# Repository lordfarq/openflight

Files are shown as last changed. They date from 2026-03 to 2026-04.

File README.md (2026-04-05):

<p align="center">

  DIY Golf Launch Monitor using the OPS243-A Doppler Radar.
</p>

<p align="center">
  <a href="https://buymeacoffee.com/colemangolfs">
    
  </a>
</p>

> [!WARNING]
> **This project is in active development.** Features may be incomplete, unstable, or change without notice. Contributions and bug reports are welcome!

## Overview

OpenFlight is an open-source golf launch monitor that uses Doppler radar to measure ball speed, club speed, launch angle, spin rate, and carry distance.

### What It Measures

- **Ball Speed**: 30-220 mph range with ±0.5% accuracy (OPS243-A)
- **Club Speed**: Detected from pre-impact readings (OPS243-A)
- **Smash Factor**: Ball speed / club speed ratio
- **Launch Angle**: Vertical launch measured by K-LD7 angle radar
- **Club Path**: Horizontal aim direction measured by second K-LD7
- **Spin Rate**: Via rolling buffer I/Q analysis (~50-60% detection rate)
- **Carry Distance**: Computed from ball speed, launch angle, and spin

### Hardware at a Glance

| Component | What it does | ~Cost |
|---|---|---|
| OPS243-A Radar | Ball speed, club speed, spin | $249 |
| Raspberry Pi 5 | Runs everything | $60 |
| 7" Touchscreen | Shows shot data | $46 |
| SparkFun SEN-14262 | Sound trigger for spin detection | $18 |
| K-LD7 + EVAL Board (×2) | Launch angle + club path | $400 |
| Power supply + accessories | | $27 |
| **Total** | | **~$800** |

> The K-LD7 angle radars are optional. Without them you still get ball speed, club speed, smash factor, spin rate, and estimated carry. See the [full parts list](docs/PARTS.md) for details and links.

## Getting Started

### 1. Get the parts

See the **[Parts List](docs/PARTS.md)** for everything you need with purchase links.

### 2. Wire it up

Follow the **[Sound Trigger Wiring Guide](docs/sound-trigger-wiring.md)** to connect the SEN-14262 to the OPS243-A. The K-LD7 modules connect via USB — no wiring needed.

### 3. Set up the Pi

Follow the **[Raspberry Pi Setup Guide](docs/raspberry-pi-setup.md)** for OS installation, software setup, radar configuration, and auto-start.

### 4. Hit balls

```bash
# Default: rolling buffer mode with sound trigger
scripts/start-kiosk.sh

# With K-LD7 angle radar
scripts/start-kiosk.sh --kld7 --kld7-angle-offset 13

# Development mode (no hardware)
scripts/start-kiosk.sh --mock
```

Then open http://localhost:8080 or use the touchscreen.

## How It Works

### System Architecture

```
┌─────────────┐  USB/Serial  ┌─────────────┐  Callback   ┌─────────────┐  WebSocket  ┌─────────────┐
│  OPS243-A   │ ───────────▶ │   Launch    │ ──────────▶ │   Flask     │ ──────────▶ │   React     │
│   Radar     │  Speed data  │   Monitor   │  on_shot()  │   Server    │   "shot"    │     UI      │
└─────────────┘              └─────────────┘             └─────────────┘             └─────────────┘
                                                               ▲
┌─────────────┐  USB/Serial                                    │
│ K-LD7 (×2)  │ ──────────────────── angle data ──────────────┘
│ Angle Radar │
└─────────────┘
```

1. **Sound trigger fires** — SEN-14262 detects club impact, triggers OPS243-A HOST_INT
2. **OPS243-A dumps buffer** — Rolling buffer I/Q data is captured and analyzed for ball speed, club speed, and spin
3. **K-LD7 correlates** — The server uses the OPS243-A impact timestamp to find the matching ball burst in the K-LD7 ring buffer, extracting launch angle and club path
4. **Carry computed** — Ball speed + spin + launch angle → carry distance
5. **UI updates** — Shot data emitted via WebSocket to the React frontend

### Doppler Radar Basics

The OPS243-A transmits a 24 GHz signal. When it bounces off a moving object (the golf ball), the frequency shifts proportionally to the object's speed — this is the Doppler effect. At 24.125 GHz, each 1 mph of speed creates a ~71.7 Hz Doppler shift.

### Positioning

Place the radar **3-5 feet behind the tee**, pointing at the hitting area:

```
                Ball Flight Direction
                ======================>

[Tee]  ←--- 3-5 ft ---→  [OPS243-A]  [K-LD7 vertical]  [K-LD7 horizontal]
```

The K-LD7 modules are positioned near the OPS243-A, one mounted vertically (launch angle) and one horizontally (club path / aim direction).

## Configuration

### Radar Settings for Golf

| Setting | Value | Why |
| --- | --- | --- |
| Sample Rate | 20 kHz | Supports up to ~139 mph |
| Buffer Size | 512 | Faster updates (~10-15 Hz)  |
| Min Speed | 10 mph | Filter slow movements |
| Direction | Outbound | Ball moving away from radar |
| Power | Max (0)  | Best detection range |

### Python API

```python
from openflight import LaunchMonitor

with LaunchMonitor() as monitor:
    print("Swing when ready...")
    shot = monitor.wait_for_shot(timeout=60)

    if shot:
        print(f"Ball Speed: {shot.ball_speed_mph:.1f} mph")
        print(f"Est. Carry: {shot.estimated_carry_yards:.0f} yards")
```

## Limitations

- **Cosine error**: If ball doesn't travel directly toward/away from radar, measured speed will be slightly lower than actual
- **Spin detection**: ~50-60% reliable — depends on signal quality and trigger timing
- **K-LD7 speed aliasing**: The K-LD7 max speed is 62 mph, so it's used only for angle/distance, not speed

## Project Structure

```
openflight/
├── src/openflight/
│   ├── ops243.py              # OPS243-A radar driver
│   ├── launch_monitor.py      # Shot detection & club/ball separation
│   ├── server.py              # Flask server, K-LD7 correlation, carry
│   ├── session_logger.py      # JSONL session logging
│   ├── kld7/                  # K-LD7 angle radar
│   │   ├── tracker.py         # Ring buffer, ball/club detection
│   │   └── types.py           # Data types
│   └── rolling_buffer/        # Spin rate detection
│       ├── monitor.py         # Rolling buffer monitor
│       ├── processor.py       # I/Q processing for spin
│       ├── trigger.py         # Trigger strategies
│       └── types.py           # Data types
├── ui/                        # React frontend
├── scripts/                   # Utility & setup scripts
├── docs/                      # Documentation
└── pyproject.toml
```

## Contributing

Contributions welcome! See [CONTRIBUTING.md](CONTRIBUTING.md) for guidelines.

Areas of interest:

- **Better spin detection**: Increase reliability beyond 50-60%
- **K-LD7 signal processing**: Improve ball detection from sparse radar frames
- **Mobile app**: Bluetooth connection to phone

### Running Tests

```bash
uv run pytest tests/ -v
```

## Documentation

- **[Parts List](docs/PARTS.md)** — What to buy
- **[Sound Trigger Wiring](docs/sound-trigger-wiring.md)** — How to wire the sound trigger
- **[Raspberry Pi Setup](docs/raspberry-pi-setup.md)** — Full setup guide
- **[Rolling Buffer & Spin Detection](docs/rolling_buffer_spin_detection.md)** — Spin measurement details
- **[K-LD7 Ball Detection Theory](docs/kld7-ball-detection-theory.md)** — How angle detection works
- **[K-LD7 Session Review](docs/kld7-session-review.md)** — Offline review workflow for session JSONL files
- **[Observability & Log Shipping](docs/observability.md)** — Ship logs to Grafana Cloud
- **[Contributing Guide](CONTRIBUTING.md)** — How to contribute
- **[Changelog](docs/CHANGELOG.md)** — Version history

## License

MIT License - see LICENSE file.

## Acknowledgments

- [OmniPreSense](https://omnipresense.com/) for the OPS243-A radar and documentation
- The golf hacker community for inspiration

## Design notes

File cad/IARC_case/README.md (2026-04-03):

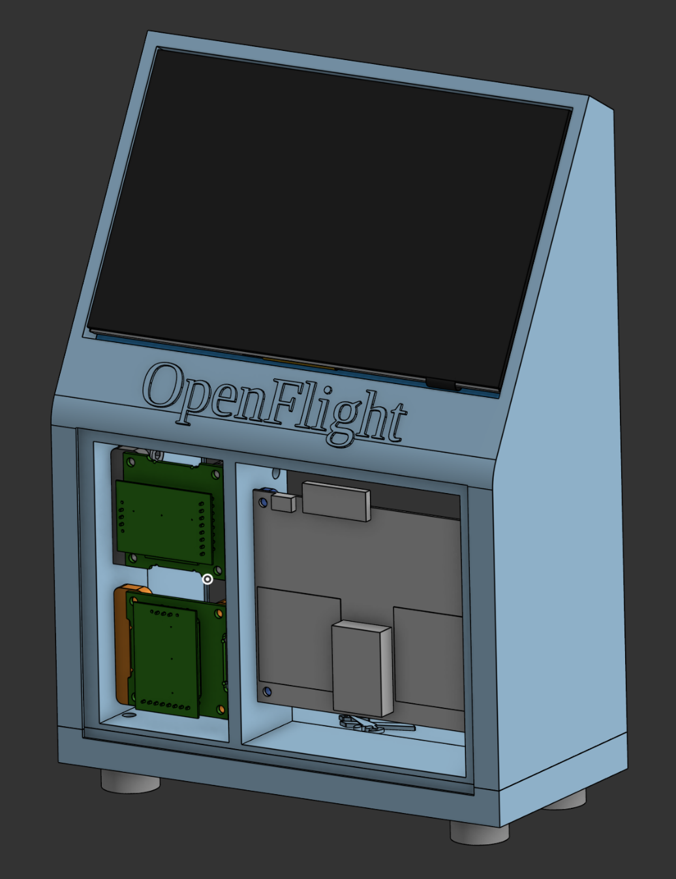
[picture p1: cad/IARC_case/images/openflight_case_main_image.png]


M5 Bolts needed: 18
Front piece of glass size: 166mm width x 115mm length x 2mm thick
Back piece of glass size: 166mm width x 225mm length x 2mm thick

Instructions for OpenFlight Case Build
  
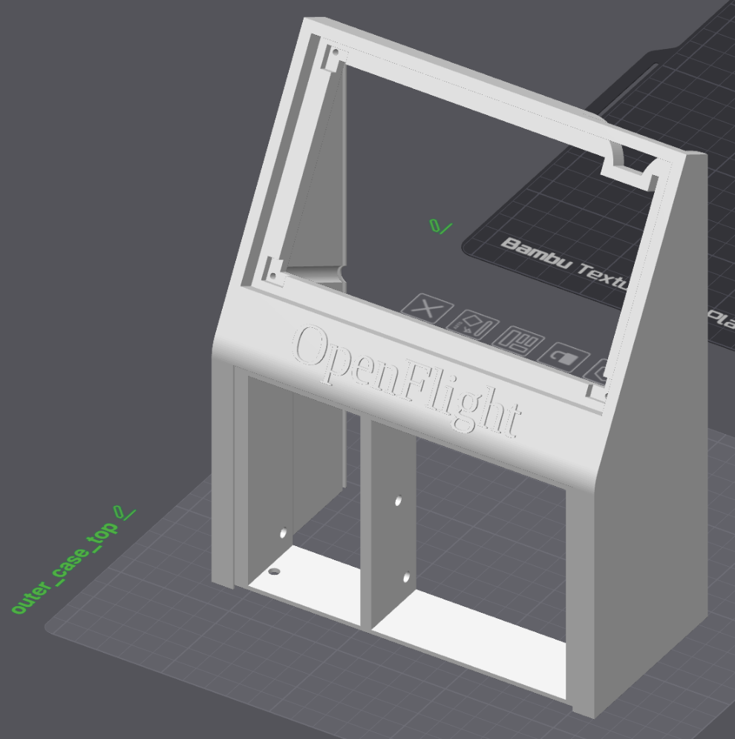
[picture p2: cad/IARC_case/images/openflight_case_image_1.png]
1. Start by printing (1x) ```outer_case_top.stl```. This part will house pretty much everything. 
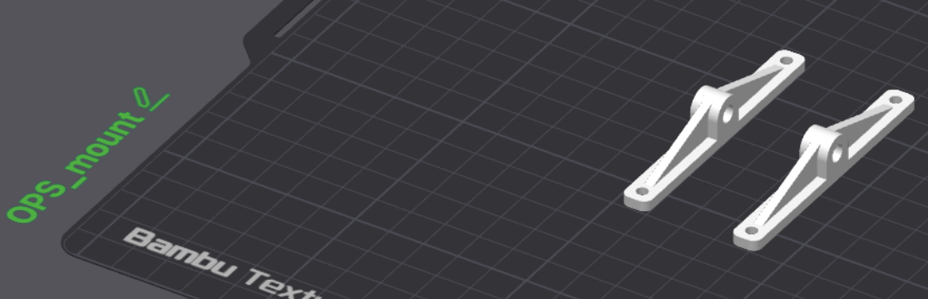
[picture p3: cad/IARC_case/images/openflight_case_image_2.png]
2. Print (2x) ```OPS_mount``` parts. These secure onto the OPS243 sensor.
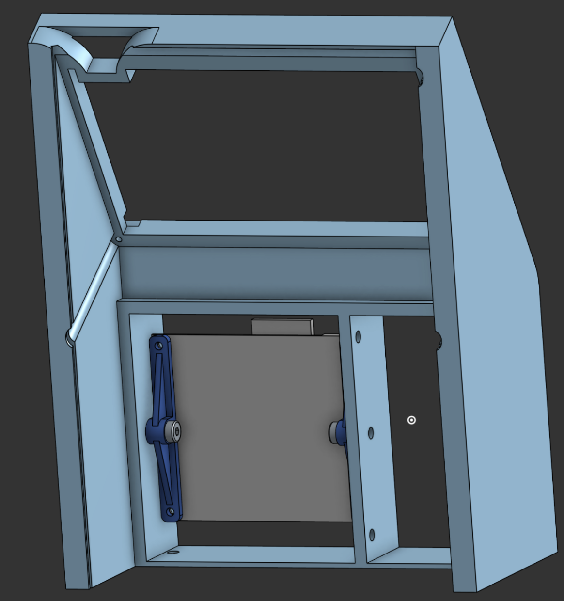
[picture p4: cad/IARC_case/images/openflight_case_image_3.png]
3. Once both mounts are secured to the OPS sensor, use (2x) M5 bolts to screw the entire OPS assembly into the larger left side of the outer_case_top part. Make sure the OPS assembly doesn’t protrude beyond the wall of the ```outer_case_top``` part. NOTE: I don’t know what screws are used for the OPS board itself…
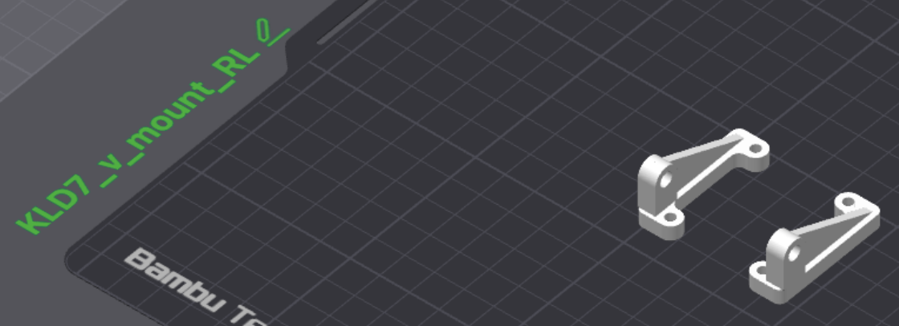
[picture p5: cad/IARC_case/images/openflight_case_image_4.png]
4. Print (1x) ```KLD7_v_mount_L.stl``` and (1x) ```KLD7_v_mount_R.stl```. These will mount to one of the KLD7 sensors, and secure it in the vertical position.
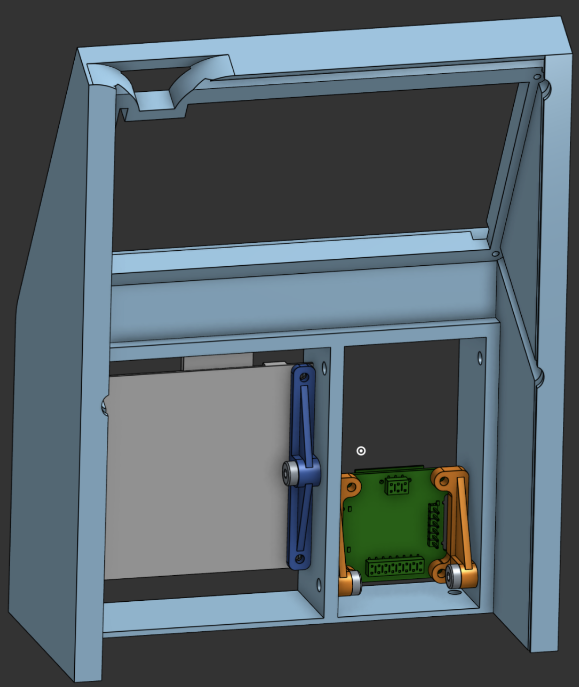
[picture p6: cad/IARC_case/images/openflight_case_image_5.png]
5. Use (2x) M5 bolts to secure the vertical KLD7 assembly into the lower section on the right side of the ```outer_case_top``` part.
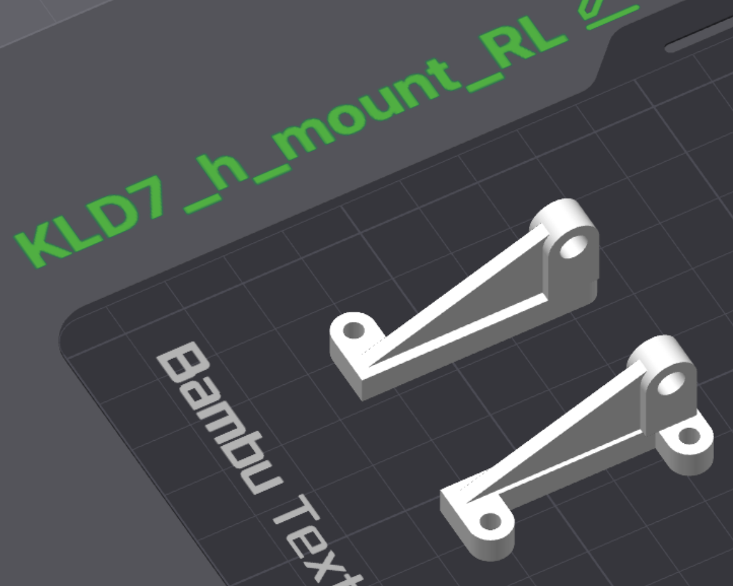
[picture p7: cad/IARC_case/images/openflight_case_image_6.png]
6. Print (1x) ```KLD7_h_mount_L.stl``` and (1x) ```KLD7_h_mount_R.stl```. These will mount to the other KLD7 sensor, and secure it in the horizontal position.
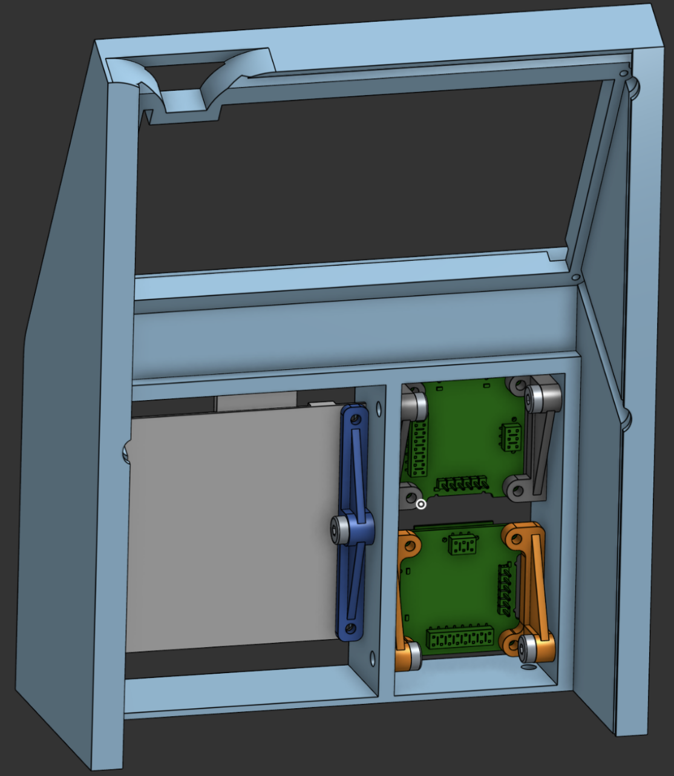
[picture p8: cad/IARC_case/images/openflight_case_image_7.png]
7. Use (2x) M5 bolts to secure the horizontal KLD7 assembly into the upper section on the right side of the ```outer_case_top part```.
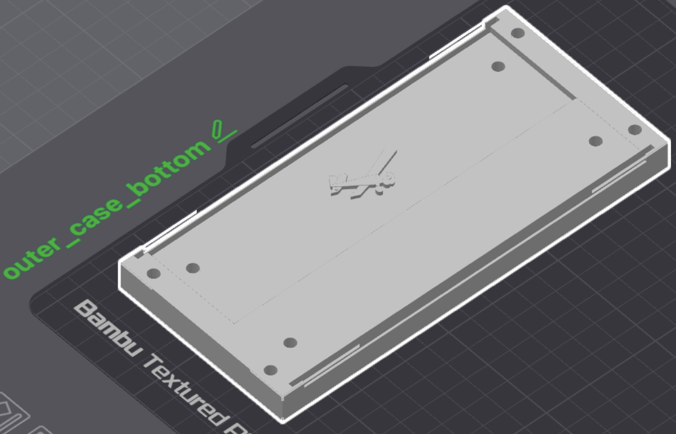
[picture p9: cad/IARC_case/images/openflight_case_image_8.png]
8. Print out (1x) ```outer_case_bottom.stl``` 
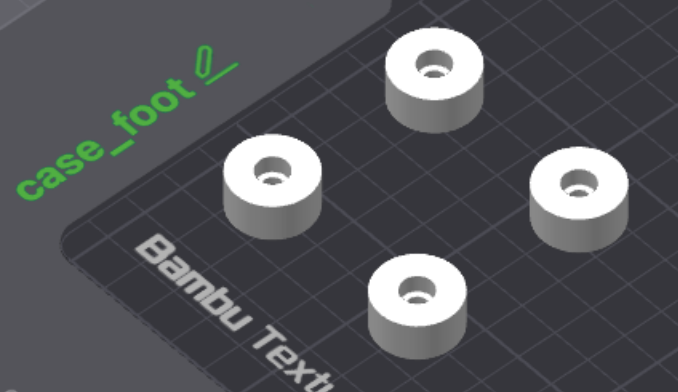
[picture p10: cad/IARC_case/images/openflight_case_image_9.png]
9. Print out (4x) ```case_foot.stl``` parts.
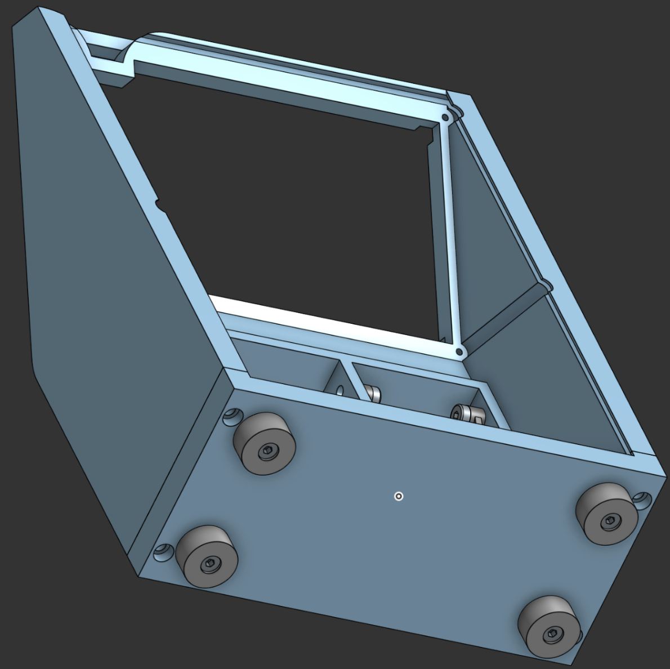
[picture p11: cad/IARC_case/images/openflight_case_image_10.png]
10. Use (4x) M5 bolts to secure each ```case_foot``` part to the underside of the ```outer_case_bottom``` part. 
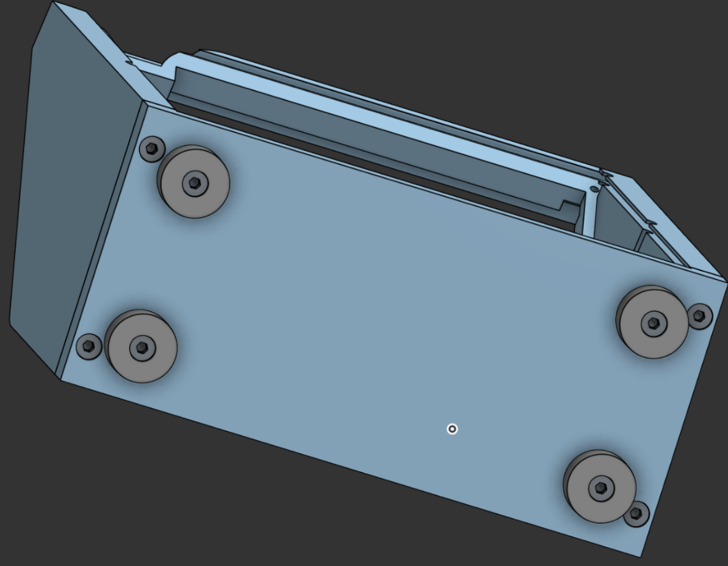
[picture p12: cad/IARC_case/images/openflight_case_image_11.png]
11. Use (4x) M5 bolts to secure the ```outer_case_bottom``` to the ```outer_case_top part```. 

And that’s how you put together the 3d printed parts!

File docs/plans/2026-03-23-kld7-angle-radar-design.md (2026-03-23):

# K-LD7 Angle Radar Integration — Design

**Date:** 2026-03-23
**Status:** Exploration phase

## Goal

Add an RFbeam K-LD7 24GHz FMCW radar module to supplement the OPS243-A Doppler radar. The OPS243 handles speed and spin detection. The K-LD7 provides per-target **angle**, **distance**, and **magnitude** data that the OPS243 cannot.

Long-term, the K-LD7 may replace the camera for horizontal angle measurement and provide distance-to-target data. This phase is data gathering only.

## K-LD7 Module Overview

- **Frequency:** 24 GHz ISM band (same as OPS243)
- **Modulation:** FMCW (vs OPS243's CW Doppler)
- **Beam:** H80° × V34° (datasheet: ±40° H, ±17° V at -3dB)
- **Measurements per target:** distance (m), speed (km/h), horizontal angle (°), magnitude
- **Multi-target:** PDAT returns all detected targets; TDAT returns the strongest
- **Interface:** UART, 115200 baud default (even parity), up to 3 Mbaud
- **Power:** 5V, 200mA
- **Range settings:** 5m / 10m / 30m / 100m
- **Speed settings:** 12.5 / 25 / 50 / 100 km/h (max 62 mph — below golf ball speed)
- **Angle range:** -90° to +90° horizontal
- **Driver:** `nickovs/kld7` Python library (pip install kld7)

## Known Limitations

1. **Speed aliasing (not just saturation):** Max 100 km/h (62 mph). The datasheet warns that speeds above the max setting produce *wrong measurements* due to aliasing — not just clipped values. Golf balls at 150+ mph will report incorrect speeds. This is acceptable since OPS243 handles speed. Angle and distance should still be valid.
2. **Very few frames per shot:** At 100 km/h speed setting, frame duration is ~29ms (~34 fps). A golf ball transits the 5m detection zone in ~30ms, giving only 1-2 frames per shot. PDAT (raw detections) is more reliable than TDAT (tracked target) since the tracking filter likely won't lock on in time.
3. **Horizontal angle only:** No vertical angle measurement. Vertical launch angle still requires camera or estimation. A second K-LD7 mounted at 90° could provide vertical angle (future consideration).
4. **Interference potential:** Both radars operate at 24 GHz. May need frequency offset via K-LD7's RBFR parameter (low/mid/high base frequency).
5. **Tracking filter limitations:** Tracks only 1 target with 30m max range. For multi-target scenarios or fast transients, rely on PDAT raw data instead.

## Phase 1: Test Script

### `scripts/test_kld7.py`

Standalone script for data gathering. No integration with the server or OPS243 yet.

**Behavior:**
1. Connect to K-LD7 via USB serial (EVAL board)
2. Configure for golf use case (short range, max speed, both directions)
3. Stream TDAT + PDAT + RFFT frames continuously
4. Print live target data to terminal
5. Save all frames to `.pkl` on Ctrl+C

**Configuration for golf:**
- `RSPI = 3` — 100 km/h max speed
- `RRAI = 0` — 5m range (ball is close to radar)
- `DEDI = 2` — both approaching and receding
- `THOF = 10` — low threshold for sensitivity
- `TRFT = 1` — fast detection (ball is transient)

**Output format (.pkl):**
```python
{
    "metadata": {
        "module": "K-LD7",
        "capture_start": "<iso timestamp>",
        "capture_end": "<iso timestamp>",
        "total_frames": N,
        "params": {"RSPI": 3, "RRAI": 0, ...},
    },
    "frames": [
        {
            "timestamp": <float>,
            "tdat": {"distance": 1.23, "speed": 45.2, "angle": 3.1, "magnitude": 500},
            "pdat": [{"distance": ..., "speed": ..., "angle": ..., "magnitude": ...}, ...],
            "rfft": [[256 bins], [256 bins]],
        },
        ...
    ]
}
```

**CLI args:**
- `--port` — serial port (auto-detect if omitted)
- `--range` — range setting: 5, 10, 30, 100 (default: 5)
- `--speed` — max speed: 12, 25, 50, 100 km/h (default: 100)
- `--baud` — baud rate (default: 115200)
- `--no-fft` — skip RFFT frames (smaller output, faster)
- `-o, --output` — output .pkl path (default: auto-generated in ~/openflight_sessions/)
- `-n, --max-frames` — stop after N frames (default: unlimited)

**Connection:** USB via EVAL board → `/dev/ttyUSB*` on Pi.

### Datasheets

- `docs/K-LD7_Datasheet.pdf` — Module datasheet
- `docs/K-LD7-EVAL_Datasheet.pdf` — EVAL board datasheet

## Future Phases (not in scope now)

- **Phase 2:** Side-by-side capture with OPS243 — correlate K-LD7 angle data with OPS243 speed/spin data on same shots
- **Phase 3:** Integration module (`src/openflight/kld7/`) with real-time angle injection into shots
- **Phase 4:** Evaluate replacing camera with K-LD7 for horizontal angle; consider second K-LD7 for vertical

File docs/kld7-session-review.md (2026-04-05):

# K-LD7 Session Review

This workflow is for reviewing a full `session_logs/session_*.jsonl` file after a K-LD7 tuning change.

It is intentionally an **offline empirical review tool**, not a live detector.

## What It Does

For each shot in a session log, the review script:

1. parses `rolling_buffer_capture`, `kld7_buffer`, and `shot_detected` rows by `shot_number`
2. re-detects likely club-impact anchors directly from the raw K-LD7 frame buffer
3. scores outward post-impact `pdat` paths by:
   - timing after impact
   - distance growth
   - angle continuity
   - magnitude strength
   - lingering-clutter penalties
4. keeps the best path per shot
5. exports per-shot and session-level plots

The result is a quick way to see whether a session contains real-looking ball-flight distance profiles or mostly clutter.

## How The Grades Are Used

The exported `strong`, `partial`, and `weak` labels are **review grades for signal recoverability**:

- `strong`: the session produced a coherent outward path that is good evidence for a real tracked shot
- `partial`: the session exposed part of the shot pattern, but the path is short or noisy
- `weak`: the reviewed path is mostly clutter or too incomplete to trust

These grades are for K-LD7 review and tuning. They are **not** grades of player performance, shot outcome, or launch-angle correctness by themselves.

## Usage

For a one-off review on any machine, run the script in an isolated `uv`
environment with only the analysis dependencies it needs:

```bash
uv run --no-project --with numpy --with matplotlib python scripts/review_kld7_session.py session_logs/session_20260403_133805_range.jsonl
```

If you already have the repo environment synced with the analysis extras, the
regular project command also works:

```bash
uv run python scripts/review_kld7_session.py session_logs/session_20260403_133805_range.jsonl
```

If you want to remove previously generated files in the output directory first,
use `--clean`. Cleanup is intentionally restricted to directories that look like
`<repo>/shots/session_review_*`.

```bash
uv run --no-project --with numpy --with matplotlib python scripts/review_kld7_session.py session_logs/session_20260403_133805_range.jsonl --clean
```

Default output location:

```text
<repo>/shots/session_review_session_20260403_133805_range/
```

That directory is ignored by git.

## Generated Files

- `shot_01_profile.png` ... `shot_N_profile.png`
- `all_shot_profiles_overlay.png`
- `launch_angle_review.png`
- `shot_profiles.csv`
- `summary.md`

## How To Read The Plots

Per-shot plot:

- gray points: all post-impact detections in the selected review window
- black connected line: the chosen coherent path
- orange dashed line: path angle trace
- green lower panel: path magnitude over time

Overlay plot:

- blue: stronger reviewed profiles
- orange: partial profiles
- red: weak/noisy profiles
- black line + gold band: median path and IQR across the session

## Interpretation Rules

Treat a shot as stronger evidence when it shows:

- multiple consecutive frames
- outward distance growth
- limited angle jump
- no obvious lingering return at the same far location afterward

Treat a shot as weak evidence when it:

- starts already deep in a far clutter band
- stays almost flat in distance
- shows only one noisy frame
- leaves obvious lingering returns after the burst

## Limits

- This is not a physics model.
- The inferred impact anchor is heuristic.
- The path angle trace is a secondary diagnostic, not ground truth.
- A single improved session supports further study, but does not by itself validate a K-LD7 tuning change.

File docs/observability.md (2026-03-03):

# Observability & Log Shipping

OpenFlight can ship session logs to Grafana Cloud for long-term storage, querying, and dashboarding. This uses [Grafana Alloy](https://grafana.com/docs/alloy/) to tail JSONL session files and push them to Loki.

## Overview

```
Session Logs (JSONL)  →  Grafana Alloy  →  Grafana Cloud Loki  →  Grafana Dashboards
~/openflight_sessions/     (local agent)       (cloud storage)       (query & visualize)
```

- **What gets shipped**: Every JSONL entry — session start/end, shot data (ball speed, club speed, spin, launch angle, carry), trigger events, I/Q readings
- **Labels**: `app=openflight`, `host=<hostname>`, `log_type` (shot_detected, session_start, etc.), `mode`, `club`
- **Extracted fields**: `ball_speed`, `club_speed`, `carry`, `spin_rpm`, `launch_v`, `launch_h`, `shot_number`
- **Buffering**: Local WAL (write-ahead log) buffers during network outages

## Setup

### Prerequisites

- Raspberry Pi running OpenFlight
- A [Grafana Cloud](https://grafana.com/products/cloud/) account (free tier works)

### 1. Get Grafana Cloud Credentials

1. Log in to [Grafana Cloud](https://grafana.com/)
2. Go to your stack → **Connections** → **Loki**
3. Click **Details** to find:
   - **URL**: Loki push endpoint (e.g., `https://logs-prod-us-central1.grafana.net/loki/api/v1/push`)
   - **User**: Numeric instance ID
4. Generate an **API key** with `logs:write` scope

### 2. Install Alloy

```bash
sudo ./scripts/setup_alloy.sh
```

This script:
- Adds the Grafana APT repository
- Installs Grafana Alloy
- Writes the Alloy config to `/etc/alloy/config.alloy` (from `config/alloy.alloy`)
- Creates a credentials template at `/etc/alloy/credentials.env`
- Configures the systemd service to run as your user (so it can read session logs)
- Enables the Alloy service

### 3. Configure Credentials

```bash
sudo vim /etc/alloy/credentials.env
```

Fill in your Grafana Cloud values:

```env
LOKI_URL=https://logs-prod-us-central1.grafana.net/loki/api/v1/push
LOKI_USER=123456
LOKI_API_KEY=glc_your_api_key_here
```

### 4. Start Alloy

```bash
sudo systemctl start alloy
```

Or just run `scripts/start-kiosk.sh` — it starts Alloy automatically if credentials are configured.

### 5. Verify

Check Alloy is running:

```bash
sudo systemctl status alloy
```

Check for errors:

```bash
sudo journalctl -u alloy -f
```

Then query in Grafana Cloud → Explore → Loki:

```logql
{app="openflight"}
```

## Querying Session Data

### Basic Queries (LogQL)

```logql
# All shot data
{app="openflight", log_type="shot_detected"}

# Shots with a specific club
{app="openflight", log_type="shot_detected", club="driver"}

# Session starts
{app="openflight", log_type="session_start"}

# Filter by ball speed (using JSON parsing)
{app="openflight", log_type="shot_detected"} | json | ball_speed_mph > 150
```

### Metric Queries

```logql
# Average ball speed over time
avg_over_time({app="openflight", log_type="shot_detected"} | json | unwrap ball_speed_mph [1h])

# Shot count per session
count_over_time({app="openflight", log_type="shot_detected"} [24h])

# Spin detection rate (shots with spin > 0)
count_over_time({app="openflight", log_type="shot_detected"} | json | spin_rpm > 0 [24h])
```

## How It Works

### Session Log Format

OpenFlight writes JSONL files to `~/openflight_sessions/session_<timestamp>_<mode>.jsonl`. Each line is a JSON object with a `type` field:

| Entry Type | Description | Key Fields |
|---|---|---|
| `session_start` | Session began | `mode`, `camera_enabled`, `sample_rate` |
| `session_end` | Session ended | `duration_seconds`, `total_shots` |
| `shot_detected` | A shot was detected | `ball_speed_mph`, `club_speed_mph`, `spin_rpm`, `launch_angle_vertical`, `estimated_carry_yards` |
| `trigger_event` | Trigger accepted/rejected | `accepted`, `latency_ms`, `trigger_type` |
| `rolling_buffer_capture` | Raw I/Q capture | `num_samples`, `sample_rate` |

### Alloy Pipeline

The config at `config/alloy.alloy` defines a three-stage pipeline:

1. **File Discovery** (`local.file_match`): Watches for `session_*.jsonl` files
2. **JSON Processing** (`loki.process`): Extracts fields as labels and structured metadata, uses the `ts` field as the log timestamp
3. **Loki Push** (`loki.write`): Ships to Grafana Cloud with basic auth and retry on rate-limiting

### Auto-Start

When `scripts/start-kiosk.sh` runs, it checks:
1. Is Alloy installed?
2. Is `/etc/alloy/credentials.env` configured (not empty)?
3. Is the Alloy service already running?

If credentials are configured but Alloy isn't running, it starts the service automatically.

## Troubleshooting

### "Alloy installed but no credentials file found"

Run the setup script:

```bash
sudo ./scripts/setup_alloy.sh
```

Then fill in `/etc/alloy/credentials.env`.

### "Alloy installed but credentials not configured"

The credentials file exists but has empty values. Edit it:

```bash
sudo vim /etc/alloy/credentials.env
```

### 401 Unauthorized

Your API key is invalid or missing the `logs:write` scope. Generate a new key in Grafana Cloud → Loki → Details.

### Permission Denied on Config

```bash
sudo chmod 755 /etc/alloy
sudo chmod 644 /etc/alloy/config.alloy
sudo chmod 600 /etc/alloy/credentials.env
```

### Alloy Won't Start (CHDIR Error)

The data directory may not exist:

```bash
sudo mkdir -p /var/lib/alloy/data
sudo chown -R $(whoami):$(whoami) /var/lib/alloy
```

### No Logs Appearing in Grafana

1. Verify Alloy is running: `sudo systemctl status alloy`
2. Check Alloy logs: `sudo journalctl -u alloy -f`
3. Verify session logs exist: `ls ~/openflight_sessions/`
4. Make sure session logging is enabled (it's on by default, including mock mode)

## Configuration Reference

### Files

| File | Purpose |
|---|---|
| `config/alloy.alloy` | Alloy pipeline config (source of truth) |
| `config/credentials.env.example` | Credentials template |
| `/etc/alloy/config.alloy` | Deployed config (written by setup script) |
| `/etc/alloy/credentials.env` | Deployed credentials (user fills in) |
| `scripts/setup_alloy.sh` | Installation and setup script |

### Environment Variables

| Variable | Description |
|---|---|
| `LOKI_URL` | Grafana Cloud Loki push endpoint |
| `LOKI_USER` | Grafana Cloud instance ID (numeric) |
| `LOKI_API_KEY` | API key with `logs:write` scope |

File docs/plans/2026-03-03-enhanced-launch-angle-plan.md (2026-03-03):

# Enhanced Launch Angle Estimation — Implementation Plan

> **For Claude:** REQUIRED SUB-SKILL: Use superpowers:executing-plans to implement this plan task-by-task.

**Goal:** Improve launch angle estimation by incorporating smash factor and spin rate, then wire launch angle into carry distance calculation.

**Architecture:** Enhance `estimate_launch_angle()` in `server.py` to accept optional club_speed and spin_rpm. Add `adjust_carry_for_launch_angle()` in `launch_monitor.py`. Update `Shot` properties to use the new carry adjustment. All changes are additive — no inputs = current behavior.

**Tech Stack:** Python, pytest. No new dependencies.

---

### Task 1: Enhanced launch angle estimation — smash factor adjustment

**Files:**
- Modify: `src/openflight/server.py:70-116` (the `estimate_launch_angle` function)
- Test: `tests/test_server.py`

**Step 1: Write failing tests for smash factor adjustment**

Add to `tests/test_server.py` in `TestEstimateLaunchAngle`:

```python
def test_low_smash_lowers_launch(self):
    """Low smash factor (thin hit) should lower launch angle."""
    baseline, _ = estimate_launch_angle(ClubType.DRIVER, 143)
    angle, _ = estimate_launch_angle(ClubType.DRIVER, 143, club_speed_mph=110)
    # smash = 143/110 = 1.30, well below optimal 1.48
    assert angle < baseline

def test_optimal_smash_no_change(self):
    """Optimal smash factor should not shift launch angle much."""
    baseline, _ = estimate_launch_angle(ClubType.DRIVER, 143)
    angle, _ = estimate_launch_angle(ClubType.DRIVER, 143, club_speed_mph=96.6)
    # smash = 143/96.6 ≈ 1.48 (optimal for driver)
    assert abs(angle - baseline) <= 0.5

def test_smash_raises_confidence(self):
    """Providing club speed should raise confidence from 0.2 to 0.35."""
    _, conf = estimate_launch_angle(ClubType.DRIVER, 143, club_speed_mph=96.6)
    assert conf == 0.35

def test_iron_smash_adjustment(self):
    """Iron smash factor adjustment should work correctly."""
    baseline, _ = estimate_launch_angle(ClubType.IRON_7, 100)
    # Low smash for 7-iron: smash = 100/80 = 1.25, below optimal ~1.34
    angle, _ = estimate_launch_angle(ClubType.IRON_7, 100, club_speed_mph=80)
    assert angle < baseline

def test_no_club_speed_unchanged(self):
    """Without club speed, behavior should be identical to current."""
    angle, conf = estimate_launch_angle(ClubType.DRIVER, 143)
    assert angle == 11.0
    assert conf == 0.2
```

**Step 2: Run tests to verify they fail**

Run: `uv run pytest tests/test_server.py::TestEstimateLaunchAngle -v`
Expected: FAIL — `estimate_launch_angle()` doesn't accept `club_speed_mph` parameter

**Step 3: Implement smash factor adjustment**

Update `estimate_launch_angle()` in `src/openflight/server.py`:

```python
def estimate_launch_angle(
    club: ClubType,
    ball_speed_mph: float,
    club_speed_mph: Optional[float] = None,
    spin_rpm: Optional[float] = None,
) -> tuple:
    """
    Estimate launch angle from club type, ball speed, and optional smash/spin data.

    Uses TrackMan averages as baseline, then adjusts:
    - Ball speed deviation from club average
    - Smash factor deviation from optimal (if club speed available)
    - Spin rate deviation from optimal (if spin available)

    Returns (vertical_angle, confidence).
    """
    # Baseline launch angles by club
    # Format: (avg_launch_deg, avg_ball_speed_mph, deg_per_mph_deviation)
    _CLUB_LAUNCH_MODEL = {
        ClubType.DRIVER: (11.0, 143, 0.15),
        ClubType.WOOD_3: (12.5, 135, 0.18),
        ClubType.WOOD_5: (14.0, 128, 0.20),
        ClubType.WOOD_7: (15.5, 122, 0.20),
        ClubType.HYBRID_3: (13.5, 123, 0.22),
        ClubType.HYBRID_5: (15.0, 118, 0.22),
        ClubType.HYBRID_7: (16.5, 112, 0.25),
        ClubType.HYBRID_9: (18.0, 106, 0.25),
        ClubType.IRON_2: (13.0, 120, 0.25),
        ClubType.IRON_3: (14.5, 118, 0.25),
        ClubType.IRON_4: (16.0, 114, 0.28),
        ClubType.IRON_5: (17.5, 110, 0.28),
        ClubType.IRON_6: (19.0, 105, 0.30),
        ClubType.IRON_7: (20.5, 100, 0.30),
        ClubType.IRON_8: (23.0, 94, 0.30),
        ClubType.IRON_9: (25.5, 88, 0.30),
        ClubType.PW: (28.0, 82, 0.30),
        ClubType.GW: (30.0, 76, 0.30),
        ClubType.SW: (32.0, 73, 0.30),
        ClubType.LW: (35.0, 70, 0.30),
        ClubType.UNKNOWN: (18.0, 120, 0.25),
    }

    # Optimal smash factors by club category
    _OPTIMAL_SMASH = {
        ClubType.DRIVER: 1.48,
        ClubType.WOOD_3: 1.44, ClubType.WOOD_5: 1.43, ClubType.WOOD_7: 1.42,
        ClubType.HYBRID_3: 1.39, ClubType.HYBRID_5: 1.38,
        ClubType.HYBRID_7: 1.37, ClubType.HYBRID_9: 1.36,
        ClubType.IRON_2: 1.37, ClubType.IRON_3: 1.36,
        ClubType.IRON_4: 1.35, ClubType.IRON_5: 1.34,
        ClubType.IRON_6: 1.33, ClubType.IRON_7: 1.34,
        ClubType.IRON_8: 1.33, ClubType.IRON_9: 1.33,
        ClubType.PW: 1.25, ClubType.GW: 1.23,
        ClubType.SW: 1.22, ClubType.LW: 1.20,
        ClubType.UNKNOWN: 1.35,
    }

    avg_launch, avg_speed, deg_per_mph = _CLUB_LAUNCH_MODEL.get(
        club, (18.0, 120, 0.25)
    )

    # 1. Ball speed adjustment (existing logic)
    speed_delta = ball_speed_mph - avg_speed
    adjustment = -speed_delta * deg_per_mph

    confidence = 0.2

    # 2. Smash factor adjustment (new)
    if club_speed_mph is not None and club_speed_mph > 0:
        smash = ball_speed_mph / club_speed_mph
        optimal_smash = _OPTIMAL_SMASH.get(club, 1.35)
        smash_delta = smash - optimal_smash

        # Low smash = thin/toe = lower launch: 0.4 deg per 0.01 below optimal
        # High smash = up-on-it = slightly higher: 0.2 deg per 0.01 above optimal
        if smash_delta < 0:
            adjustment += smash_delta * 100 * 0.4  # negative delta → negative adj
        else:
            adjustment += smash_delta * 100 * 0.2  # positive delta → positive adj

        confidence = 0.35

    launch_angle = max(5.0, round(avg_launch + adjustment, 1))
    return (launch_angle, confidence)
```

**Step 4: Run tests to verify they pass**

Run: `uv run pytest tests/test_server.py::TestEstimateLaunchAngle -v`
Expected: PASS

**Step 5: Commit**

```bash
git add src/openflight/server.py tests/test_server.py
git commit -m "feat: add smash factor adjustment to launch angle estimation"
```

---

### Task 2: Spin rate adjustment to launch angle

**Files:**
- Modify: `src/openflight/server.py:70-116` (the `estimate_launch_angle` function)
- Test: `tests/test_server.py`

**Step 1: Write failing tests for spin adjustment**

Add to `tests/test_server.py` in `TestEstimateLaunchAngle`:

```python
def test_high_spin_raises_launch(self):
    """High spin should nudge launch angle up."""
    baseline, _ = estimate_launch_angle(ClubType.DRIVER, 143)
    angle, _ = estimate_launch_angle(ClubType.DRIVER, 143, spin_rpm=4000)
    # 4000 rpm is above optimal ~2500 for driver at 143 mph
    assert angle > baseline

def test_low_spin_lowers_launch(self):
    """Low spin should nudge launch angle down."""
    baseline, _ = estimate_launch_angle(ClubType.DRIVER, 143)
    angle, _ = estimate_launch_angle(ClubType.DRIVER, 143, spin_rpm=1000)
    assert angle < baseline

def test_spin_with_smash_raises_confidence(self):
    """Providing both club speed and spin should raise confidence to 0.5."""
    _, conf = estimate_launch_angle(
        ClubType.DRIVER, 143, club_speed_mph=96.6, spin_rpm=2500
    )
    assert conf == 0.5

def test_spin_alone_confidence(self):
    """Spin without club speed should raise confidence to 0.35."""
    _, conf = estimate_launch_angle(ClubType.DRIVER, 143, spin_rpm=2500)
    assert conf == 0.35
```

**Step 2: Run tests to verify they fail**

Run: `uv run pytest tests/test_server.py::TestEstimateLaunchAngle::test_high_spin_raises_launch tests/test_server.py::TestEstimateLaunchAngle::test_low_spin_lowers_launch tests/test_server.py::TestEstimateLaunchAngle::test_spin_with_smash_raises_confidence tests/test_server.py::TestEstimateLaunchAngle::test_spin_alone_confidence -v`
Expected: FAIL — spin_rpm is accepted but not used yet (or not accepted at all)

**Step 3: Add spin adjustment to `estimate_launch_angle()`**

Add after the smash factor block, before the `max(5.0, ...)` line:

```python
    # 3. Spin rate adjustment (new)
    if spin_rpm is not None:
        # Use optimal spin lookup from rolling_buffer module
        from .rolling_buffer.monitor import get_optimal_spin_for_ball_speed
        optimal_spin = get_optimal_spin_for_ball_speed(ball_speed_mph, club)
        spin_delta = spin_rpm - optimal_spin

        # High spin → higher launch (~0.3 deg per 500 rpm above optimal)
        # Low spin → lower launch (~0.3 deg per 500 rpm below optimal)
        # This is a secondary signal, weighted less than smash
        adjustment += (spin_delta / 500) * 0.3

        # Bump confidence
        if confidence >= 0.35:
            confidence = 0.5  # had smash + now spin
        else:
            confidence = 0.35  # spin alone
```

**Step 4: Run tests to verify they pass**

Run: `uv run pytest tests/test_server.py::TestEstimateLaunchAngle -v`
Expected: PASS (all tests including old ones)

**Step 5: Commit**

```bash
git add src/openflight/server.py tests/test_server.py
git commit -m "feat: add spin rate adjustment to launch angle estimation"
```

---

### Task 3: Launch angle carry adjustment function

**Files:**
- Modify: `src/openflight/launch_monitor.py` (add function after `estimate_carry_distance`)
- Test: `tests/test_launch_monitor.py`

**Step 1: Write failing tests**

Add to `tests/test_launch_monitor.py`:

```python
from openflight.launch_monitor import adjust_carry_for_launch_angle

class TestAdjustCarryForLaunchAngle:
    """Tests for launch-angle-based carry distance adjustment."""

    def test_optimal_angle_no_penalty(self):
        """Optimal launch angle should return base carry unchanged."""
        # Driver optimal is ~11 degrees
        result = adjust_carry_for_launch_angle(
            base_carry=250, launch_angle=11.0, club=ClubType.DRIVER, confidence=0.5
        )
        assert result == pytest.approx(250, abs=1)

    def test_low_angle_reduces_carry(self):
        """Below-optimal launch angle should reduce carry."""
        result = adjust_carry_for_launch_angle(
            base_carry=250, launch_angle=7.0, club=ClubType.DRIVER, confidence=1.0
        )
        # 4 degrees low * 2.0 yards/deg = -8 yards
        assert result < 250
        assert result == pytest.approx(242, abs=1)

    def test_high_angle_reduces_carry(self):
        """Above-optimal launch angle should reduce carry (less severe)."""
        result = adjust_carry_for_launch_angle(
            base_carry=250, launch_angle=16.0, club=ClubType.DRIVER, confidence=1.0
        )
        # 5 degrees high * 1.5 yards/deg = -7.5 yards
        assert result < 250
        assert result == pytest.approx(242.5, abs=1)

    def test_confidence_scaling(self):
        """Low confidence should reduce the adjustment magnitude."""
        full_conf = adjust_carry_for_launch_angle(
            base_carry=250, launch_angle=7.0, club=ClubType.DRIVER, confidence=1.0
        )
        low_conf = adjust_carry_for_launch_angle(
            base_carry=250, launch_angle=7.0, club=ClubType.DRIVER, confidence=0.2
        )
        # Low confidence should produce a smaller penalty
        assert low_conf > full_conf
        # But still some penalty
        assert low_conf < 250

    def test_penalty_capped_at_10_percent(self):
        """Carry penalty should never exceed 10% of base carry."""
        result = adjust_carry_for_launch_angle(
            base_carry=250, launch_angle=0.0, club=ClubType.DRIVER, confidence=1.0
        )
        assert result >= 250 * 0.90

    def test_iron_optimal_angle(self):
        """Iron clubs should use their own optimal launch angle."""
        # 7-iron optimal is ~20.5 degrees
        result = adjust_carry_for_launch_angle(
            base_carry=150, launch_angle=20.5, club=ClubType.IRON_7, confidence=0.5
        )
        assert result == pytest.approx(150, abs=1)
```

**Step 2: Run tests to verify they fail**

Run: `uv run pytest tests/test_launch_monitor.py::TestAdjustCarryForLaunchAngle -v`
Expected: FAIL — `adjust_carry_for_launch_angle` doesn't exist

**Step 3: Implement the function**

Add to `src/openflight/launch_monitor.py` after `estimate_carry_distance()` (after line 149):

```python
def adjust_carry_for_launch_angle(
    base_carry: float,
    launch_angle: float,
    club: ClubType = ClubType.DRIVER,
    confidence: float = 1.0,
) -> float:
    """
    Adjust carry distance based on launch angle deviation from optimal.

    Deviation from optimal launch angle costs carry:
    - Too low: -2.0 yards per degree (ball doesn't get enough height)
    - Too high: -1.5 yards per degree (ball balloons, less severe)
    - Penalty is scaled by confidence and capped at 10% of base carry.

    Args:
        base_carry: Base carry distance in yards (from speed-only model)
        launch_angle: Estimated or measured launch angle in degrees
        club: Club type (determines optimal launch angle)
        confidence: Confidence in the launch angle (0-1), scales the adjustment

    Returns:
        Adjusted carry distance in yards
    """
    # Optimal launch angles by club (from TrackMan data)
    _OPTIMAL_LAUNCH = {
        ClubType.DRIVER: 11.0, ClubType.WOOD_3: 12.5,
        ClubType.WOOD_5: 14.0, ClubType.WOOD_7: 15.5,
        ClubType.HYBRID_3: 13.5, ClubType.HYBRID_5: 15.0,
        ClubType.HYBRID_7: 16.5, ClubType.HYBRID_9: 18.0,
        ClubType.IRON_2: 13.0, ClubType.IRON_3: 14.5,
        ClubType.IRON_4: 16.0, ClubType.IRON_5: 17.5,
        ClubType.IRON_6: 19.0, ClubType.IRON_7: 20.5,
        ClubType.IRON_8: 23.0, ClubType.IRON_9: 25.5,
        ClubType.PW: 28.0, ClubType.GW: 30.0,
        ClubType.SW: 32.0, ClubType.LW: 35.0,
        ClubType.UNKNOWN: 18.0,
    }

    optimal = _OPTIMAL_LAUNCH.get(club, 18.0)
    angle_delta = launch_angle - optimal

    if angle_delta < 0:
        # Too low: steeper penalty
        raw_penalty = abs(angle_delta) * 2.0
    else:
        # Too high: less severe
        raw_penalty = angle_delta * 1.5

    # Scale by confidence so low-confidence estimates have less impact
    penalty = raw_penalty * confidence

    # Cap at 10% of base carry
    max_penalty = base_carry * 0.10
    penalty = min(penalty, max_penalty)

    return base_carry - penalty
```

Also add to the `__init__.py` or the import in test to make it accessible. Update `src/openflight/__init__.py` if `adjust_carry_for_launch_angle` needs exporting.

**Step 4: Run tests to verify they pass**

Run: `uv run pytest tests/test_launch_monitor.py::TestAdjustCarryForLaunchAngle -v`
Expected: PASS

**Step 5: Commit**

```bash
git add src/openflight/launch_monitor.py tests/test_launch_monitor.py
git commit -m "feat: add launch angle carry adjustment function"
```

---

### Task 4: Wire launch angle into Shot carry properties

**Files:**
- Modify: `src/openflight/launch_monitor.py:219-248` (Shot properties)
- Test: `tests/test_launch_monitor.py`

**Step 1: Write failing tests**

Add to `tests/test_launch_monitor.py` in `TestShot`:

```python
def test_carry_adjusts_for_launch_angle(self):
    """Shot with launch angle should adjust carry distance."""
    shot_no_angle = Shot(ball_speed_mph=150.0, timestamp=datetime.now())
    shot_low_angle = Shot(
        ball_speed_mph=150.0, timestamp=datetime.now(),
        launch_angle_vertical=7.0,  # well below 11 optimal for driver
        launch_angle_confidence=1.0,
    )
    assert shot_low_angle.estimated_carry_yards < shot_no_angle.estimated_carry_yards

def test_carry_unchanged_without_launch_angle(self):
    """Shot without launch angle should use current behavior."""
    shot = Shot(ball_speed_mph=150.0, timestamp=datetime.now())
    base = estimate_carry_distance(150.0, ClubType.DRIVER)
    assert shot.estimated_carry_yards == base

def test_carry_range_tighter_with_angle(self):
    """Shot with launch angle should have tighter carry range."""
    shot_no_angle = Shot(ball_speed_mph=150.0, timestamp=datetime.now())
    shot_angle = Shot(
        ball_speed_mph=150.0, timestamp=datetime.now(),
        launch_angle_vertical=11.0,
        launch_angle_confidence=0.5,
    )
    no_angle_spread = shot_no_angle.estimated_carry_range[1] - shot_no_angle.estimated_carry_range[0]
    angle_spread = shot_angle.estimated_carry_range[1] - shot_angle.estimated_carry_range[0]
    assert angle_spread < no_angle_spread
```

**Step 2: Run tests to verify they fail**

Run: `uv run pytest tests/test_launch_monitor.py::TestShot::test_carry_adjusts_for_launch_angle tests/test_launch_monitor.py::TestShot::test_carry_unchanged_without_launch_angle tests/test_launch_monitor.py::TestShot::test_carry_range_tighter_with_angle -v`
Expected: FAIL — `estimated_carry_yards` doesn't use launch angle

**Step 3: Update Shot properties**

In `src/openflight/launch_monitor.py`, update `estimated_carry_yards`:

```python
@property
def estimated_carry_yards(self) -> float:
    """
    Estimated carry distance based on ball speed, club type,
    and launch angle (when available).
    """
    base = estimate_carry_distance(self.ball_speed_mph, self.club)
    if self.launch_angle_vertical is not None:
        return adjust_carry_for_launch_angle(
            base,
            self.launch_angle_vertical,
            self.club,
            self.launch_angle_confidence or 0.2,
        )
    return base
```

Update `estimated_carry_range`:

```python
@property
def estimated_carry_range(self) -> tuple:
    """
    Return (min, max) carry distance estimate to show uncertainty.
    """
    base = self.estimated_carry_yards
    if self.has_launch_angle:
        return (base * 0.95, base * 1.05)
    return (base * 0.90, base * 1.10)
```

(The range property is unchanged in structure but now `base` incorporates the angle adjustment.)

**Step 4: Run ALL tests to verify nothing breaks**

Run: `uv run pytest tests/ -v`
Expected: PASS (including existing carry range test which checks ±10% for shots without angle)

**Step 5: Commit**

```bash
git add src/openflight/launch_monitor.py tests/test_launch_monitor.py
git commit -m "feat: wire launch angle into carry distance calculation"
```

---

### Task 5: Update server call site to pass smash/spin data

**Files:**
- Modify: `src/openflight/server.py:697-704` (the `on_shot_detected` call site)
- Test: `tests/test_server.py`

**Step 1: Write failing test**

Add to `tests/test_server.py`:

```python
def test_estimate_passes_club_speed(self):
    """estimate_launch_angle should be called with club speed when available."""
    angle_with_smash, conf = estimate_launch_angle(
        ClubType.DRIVER, 143, club_speed_mph=96.6
    )
    angle_without, _ = estimate_launch_angle(ClubType.DRIVER, 143)
    assert conf > 0.2
    # With optimal smash, angle should be close to baseline
    assert abs(angle_with_smash - angle_without) < 1.0

def test_estimate_passes_spin(self):
    """estimate_launch_angle should accept spin data."""
    angle, conf = estimate_launch_angle(
        ClubType.DRIVER, 143, club_speed_mph=96.6, spin_rpm=2500
    )
    assert conf == 0.5
```

(These tests verify the API works — the actual call site change is in the server.)

**Step 2: Run tests to verify current state**

Run: `uv run pytest tests/test_server.py -v`
Expected: Should pass (these test the function directly)

**Step 3: Update the server call site**

In `src/openflight/server.py`, update lines 697-704:

```python
    # If no camera launch angle, estimate from club type and ball speed
    if shot.launch_angle_vertical is None and shot.mode != 'mock':
        estimated = estimate_launch_angle(
            shot.club,
            shot.ball_speed_mph,
            club_speed_mph=shot.club_speed_mph,
            spin_rpm=shot.spin_rpm,
        )
        shot.launch_angle_vertical = estimated[0]
        shot.launch_angle_horizontal = 0.0
        shot.launch_angle_confidence = estimated[1]
        logger.info("Estimated launch angle: %.1f° (conf: %.0f%%)",
                     estimated[0], estimated[1] * 100)
```

**Step 4: Run full test suite**

Run: `uv run pytest tests/ -v`
Expected: PASS

**Step 5: Commit**

```bash
git add src/openflight/server.py tests/test_server.py
git commit -m "feat: pass smash factor and spin to launch angle estimation"
```

---

### Task 6: Run full lint and test suite

**Step 1: Run ruff check**

Run: `uv run ruff check src/openflight/`
Expected: PASS (no errors)

**Step 2: Run ruff format check**

Run: `uv run ruff format --check src/openflight/`
Expected: PASS

**Step 3: Run pylint**

Run: `uv run pylint src/openflight/ --fail-under=9`
Expected: Score >= 9.0

**Step 4: Run full test suite**

Run: `uv run pytest tests/ -v`
Expected: All tests PASS

**Step 5: Fix any issues found, then commit**

```bash
git add -A
git commit -m "chore: fix lint and formatting issues"
```

(Only if there were fixes needed.)

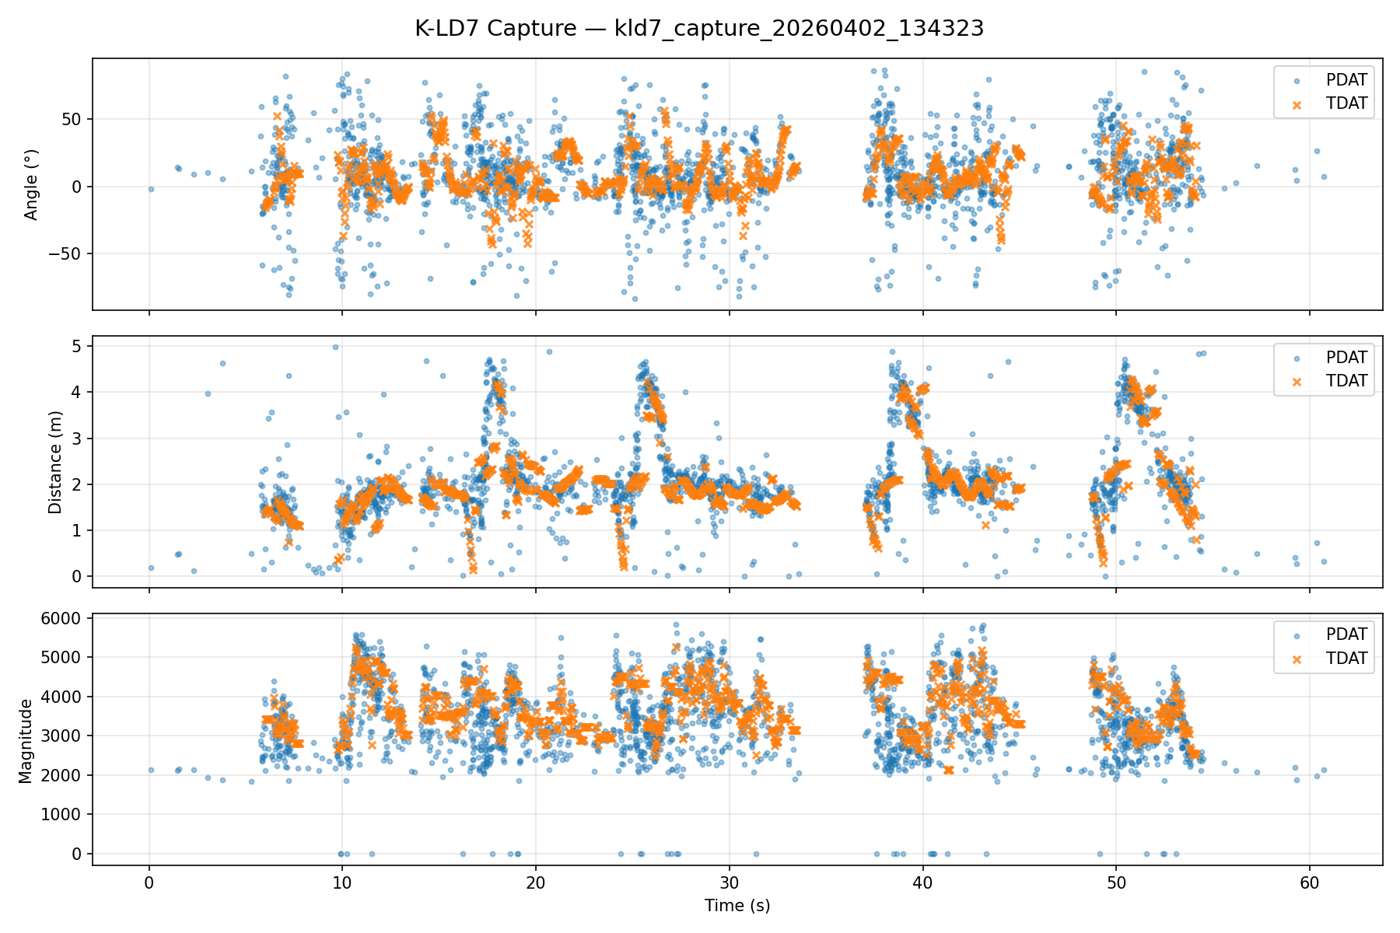
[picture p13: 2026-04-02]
session_logs/kld7_capture_20260402_134323-wedge.png

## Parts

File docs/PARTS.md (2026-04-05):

# OpenFlight Parts List

Hardware components for building the OpenFlight golf launch monitor.

> **Next step after gathering parts:** See the [Raspberry Pi Setup Guide](raspberry-pi-setup.md) for assembly and software installation.

## Core Components

| Part | Description | Link | ~Price |
|---|---|---|---|
| **OPS243-A Radar** | Doppler radar for ball/club speed detection | [OmniPreSense](https://omnipresense.com/product/ops243-a-doppler-radar-sensor/) | $249 |
| **Raspberry Pi 5** | Main compute unit (4GB+ recommended) | [Adafruit](https://www.adafruit.com/product/5812) | $60 |
| **7" Touchscreen Display** | HMTECH 7" 1024x600 IPS display | [Amazon](https://www.amazon.com/dp/B0D3QB7X4Z) | $46 |

## Sound Trigger (for Rolling Buffer Mode)

The sound trigger detects club impact to precisely time radar captures. Essential for spin detection via rolling buffer mode.

| Part | Description | Link | ~Price |
|---|---|---|---|
| **SparkFun SEN-14262** | Sound Detector with envelope/gate outputs | [SparkFun](https://www.sparkfun.com/products/14262) | $12 |
| **Through-hole resistor** | For R17 pad on SEN-14262 to reduce sensitivity (see note) | Any electronics supplier | $1 |
| **Jumper Wires** | 3 wires: GATE → HOST_INT, VCC → 3.3V, GND → GND | Any | $5 |

> **R17 resistor:** The SEN-14262 is rated for 5V but runs at 3.3V in this setup, which can cause the GATE output to stick high. Soldering a resistor into the R17 through-hole position (in parallel with the onboard 100kΩ R3) reduces preamp gain and fixes this. Start with 47kΩ; use a lower value (e.g. 33kΩ) if the sensor is still too sensitive for your environment.

### Sound Trigger Wiring

```
SEN-14262               Raspberry Pi           OPS243-A
┌───────────┐          ┌──────────┐          ┌──────────┐
│ VCC ──────┼──────────┤ 3.3V     │          │          │
│           │          │          │          │          │
│ GATE ─────┼──────────┼──────────┼──────────┤ HOST_INT │
│           │          │          │          │ (J3 P3)  │
│ GND ──────┼──────────┤ GND      ├──────────┤ GND      │
│           │          │          │          │ (J3 P1)  │
└───────────┘          └──────────┘          └──────────┘
```

See [sound-trigger-wiring.md](sound-trigger-wiring.md) for detailed instructions and troubleshooting.

## Angle Radar (K-LD7)

Two K-LD7 modules measure launch angle (vertical) and club path / aim direction (horizontal). The OPS243-A handles speed; the K-LD7s provide **angle and distance only** (speed data aliases above 62 mph).

| Part | Description | Link | ~Price |
|---|---|---|---|
| **RFbeam K-LD7 (×2)** | 24 GHz FMCW radar for angle + distance | [RFbeam](https://rfbeam.ch/product/k-ld7-radar-transceiver/) | ~$160 |
| **K-LD7 EVAL Board (×2)** | USB evaluation board for K-LD7 (FTDI serial) | [RFbeam](https://rfbeam.ch/product/k-ld7-eval-board/) | ~$240 |

### K-LD7 Connection

Each EVAL board connects via USB (FTDI serial), appearing as `/dev/ttyUSB*` on Linux.

```
K-LD7 Module → K-LD7 EVAL Board → USB → Raspberry Pi
```

One unit is mounted vertically (launch angle), one horizontally (club path / aim direction). A `--kld7-angle-offset` parameter corrects for mounting geometry — see the [setup guide](raspberry-pi-setup.md) for calibration.

## Power & Accessories

| Part | Description | Link | ~Price |
|---|---|---|---|
| **27W USB-C Power Supply** | Official Pi 5 power supply (5V 5A) | [Adafruit](https://www.adafruit.com/product/5974) | $12 |
| MicroSD Card (32GB+) | For Pi OS and software | Any Class 10 | $10 |
| USB-A to Micro-USB Cable | For OPS243-A radar connection | Any | $5 |

## Optional

| Part | Description | Link | ~Price |
|---|---|---|---|
| Tripod Mount | For positioning the unit | 1/4"-20 mount | $10 |

---

## Cost Summary

| Category | ~Price |
|---|---|
| Core (OPS243-A, Pi 5, Display) | $355 |
| Sound Trigger (SEN-14262 + resistor + wires) | $18 |
| Angle Radar (2× K-LD7 + EVAL boards) | $400 |
| Power & Accessories | $27 |
| **Total** | **~$800** |

> The angle radar is the most expensive component. OpenFlight works without it — you'll get ball speed, club speed, smash factor, and estimated carry. The K-LD7s add measured launch angle and club path data.

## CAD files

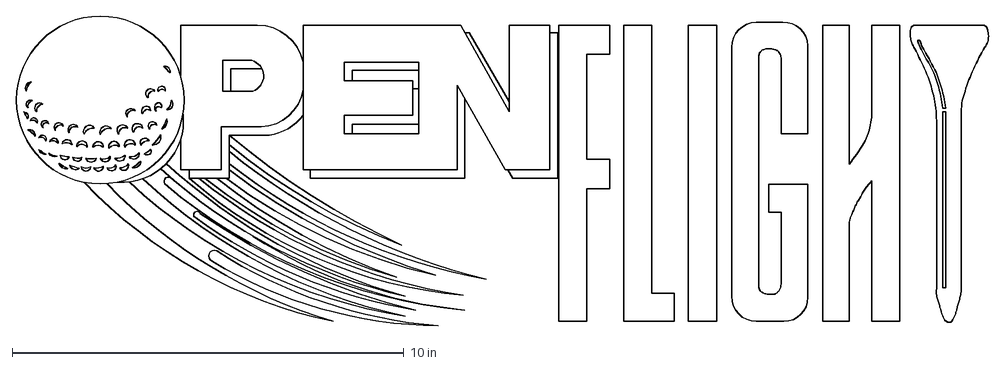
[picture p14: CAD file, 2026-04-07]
cad/LordFarq/MainLogo.DXF
24.8 x 7.90 in

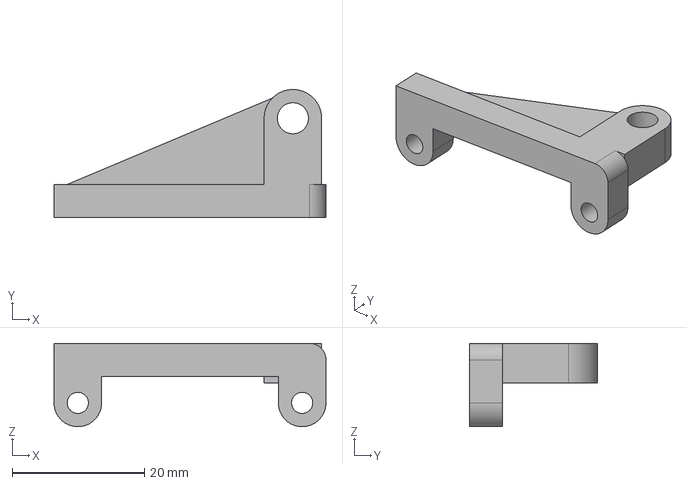
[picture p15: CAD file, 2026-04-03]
cad/IARC_case/step/KLD7_h_mount_L.step
41.1 x 19.3 x 12.6 mm

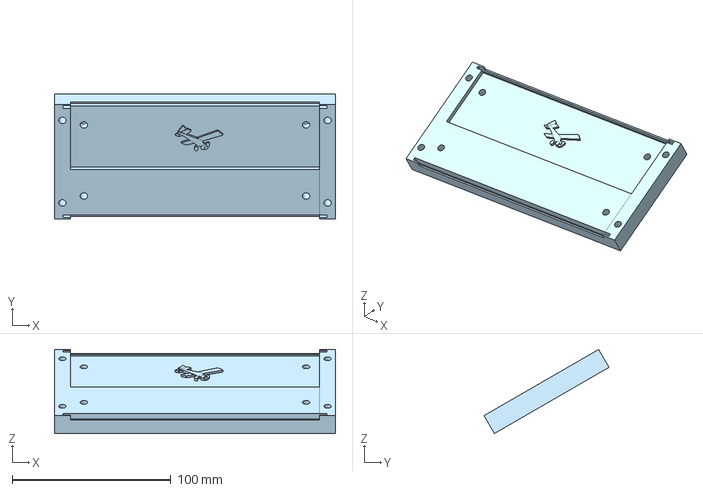
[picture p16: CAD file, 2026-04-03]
cad/IARC_case/step/outer_case_bottom.step
177.0 x 78.7 x 52.9 mm

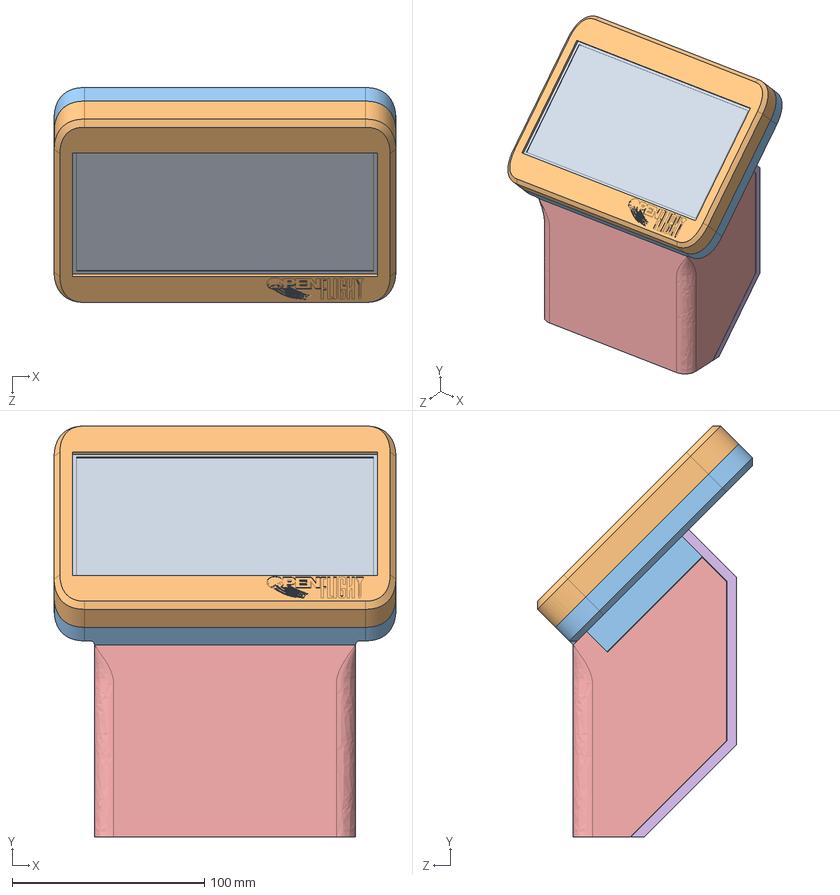
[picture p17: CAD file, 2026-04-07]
cad/LordFarq/OpenFlight.STEP
178.0 x 214.0 x 111.9 mm
Screen
ScreenBezelFront
RearScreen
OPS243
BaseFront
BaseRear

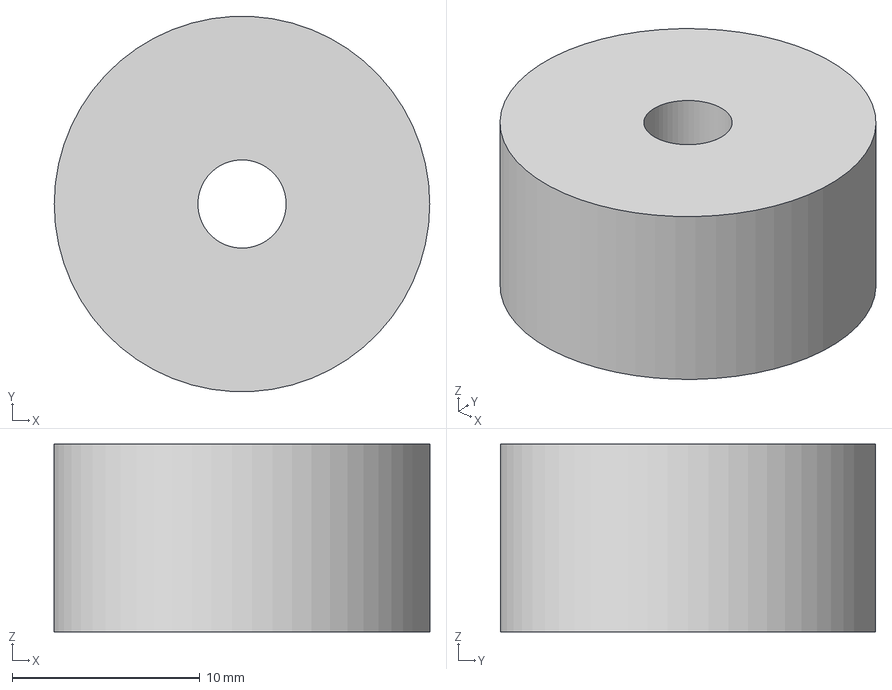
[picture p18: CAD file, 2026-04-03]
cad/IARC_case/step/case_foot.step
20.0 x 20.0 x 10.0 mm

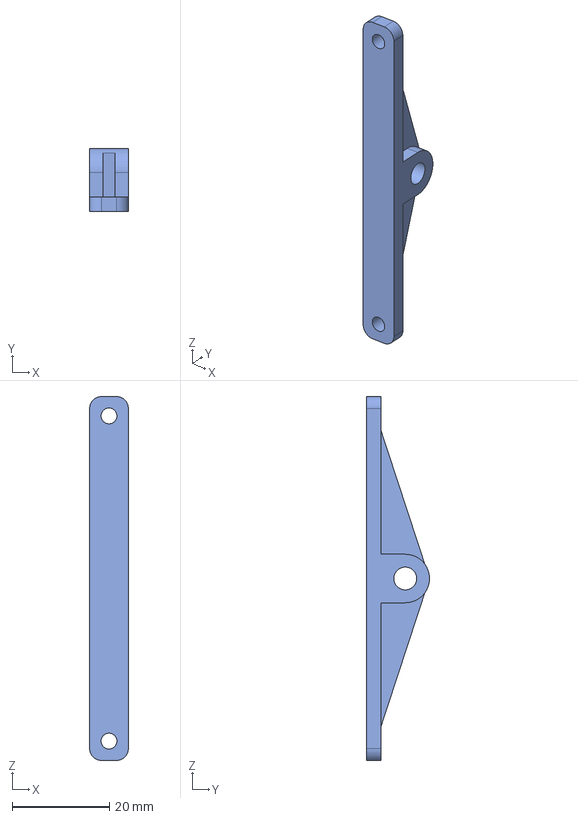
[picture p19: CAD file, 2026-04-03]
cad/IARC_case/step/OPS_mount.step
8.00 x 13.0 x 75.0 mm

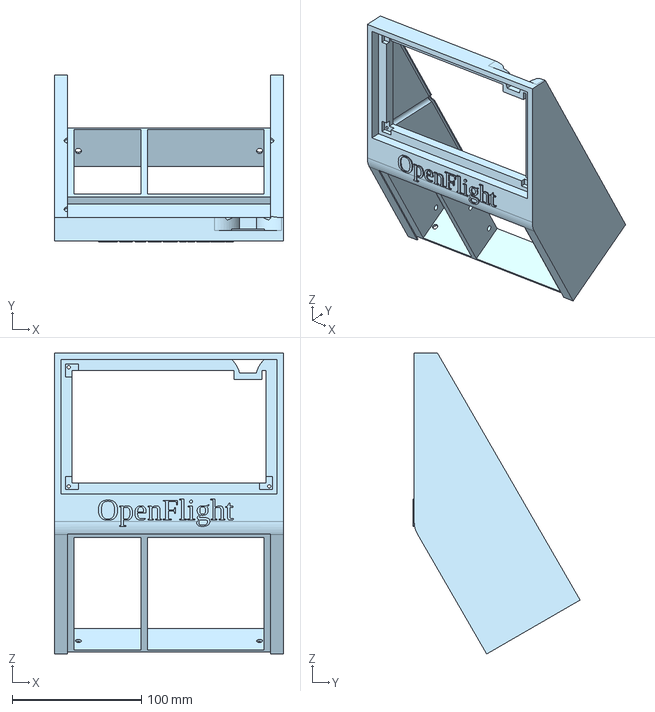
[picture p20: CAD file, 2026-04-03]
cad/IARC_case/step/outer_case_top.step
177.0 x 129.2 x 232.5 mm

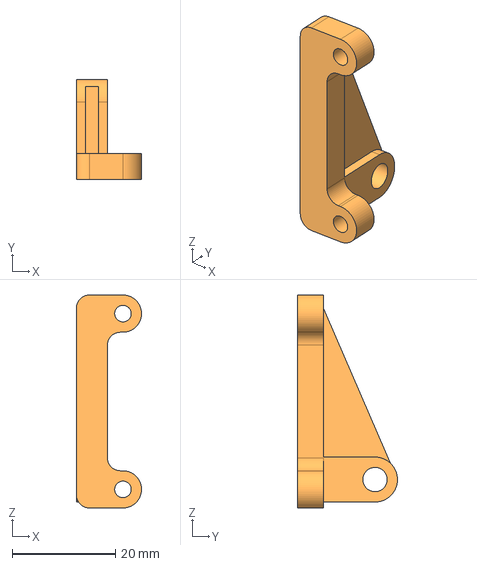
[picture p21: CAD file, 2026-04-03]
cad/IARC_case/step/KLD7_v_mount_R.step
12.6 x 19.4 x 41.2 mm

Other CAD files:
cad/IARC_case/step/KLD7_h_mount_R.step
cad/IARC_case/step/KLD7_v_mount_L.step
cad/IARC_case/stl/KLD7_h_mount_L.stl
cad/IARC_case/stl/KLD7_h_mount_R.stl
cad/IARC_case/stl/KLD7_v_mount_L.stl
cad/IARC_case/stl/KLD7_v_mount_R.stl
cad/IARC_case/stl/OPS_mount.stl
cad/IARC_case/stl/case_foot.stl
cad/IARC_case/stl/outer_case_bottom.stl
cad/IARC_case/stl/outer_case_top.stl

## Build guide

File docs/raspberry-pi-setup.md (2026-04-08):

# Raspberry Pi Setup Guide

Complete guide for setting up OpenFlight on a Raspberry Pi 5 with the 7" touchscreen display.

## Prerequisites

Make sure you have all the hardware. See the **[Parts List](PARTS.md)** for what to buy.

**Required:**
- Raspberry Pi 5 (4GB+ recommended)
- 7" Touchscreen Display
- MicroSD Card (32GB+)
- 27W USB-C Power Supply (official Pi 5 PSU recommended)
- OPS243-A Doppler Radar + USB cable
- SparkFun SEN-14262 sound detector (wired per the [Sound Trigger Wiring Guide](sound-trigger-wiring.md))

**Optional:**
- K-LD7 + FTDI adapter (×2) — for launch angle and club path (see [Parts List](PARTS.md))

## Initial Setup

### 1. Install Raspberry Pi OS

Use Raspberry Pi Imager to flash **Raspberry Pi OS (64-bit)** to your SD card.

### 2. Clone and Install

```bash
cd ~
git clone https://github.com/jewbetcha/openflight.git
cd openflight

# Run the setup script (handles everything)
./scripts/setup.sh
```

The setup script will:
- Create a Python virtual environment
- Install all Python dependencies
- Install Node.js dependencies
- Build the UI
- Run tests to verify installation

Or manually:

```bash
curl -LsSf https://astral.sh/uv/install.sh | sh
python -m venv .venv --system-site-packages
source .venv/bin/activate
uv pip install -e ".[ui]"
cd ui && npm install && npm run build && cd ..
```

## Radar Setup (One-Time)

The OPS243-A needs a one-time configuration to enable rolling buffer mode with hardware sound triggering. This saves settings to flash memory so it boots in the correct mode every time.

> **Why?** The OPS243-A has a firmware bug where the HOST_INT pin mode switches unexpectedly when entering rolling buffer mode at runtime. Saving to flash and power cycling bypasses this. Confirmed by OmniPreSense engineering.

### 1. Configure and Save

```bash
uv run python scripts/test_rolling_buffer_persist.py --setup
```

### 2. Power Cycle

Unplug the radar's USB cable, wait 3 seconds, plug it back in.

### 3. Verify

```bash
uv run python scripts/test_rolling_buffer_persist.py --test
```

Make a sound near the SEN-14262 — you should see trigger data with I/Q samples.

## K-LD7 Angle Radar Setup

Each K-LD7 connects via a 3.3V FTDI USB-to-serial adapter and appears as `/dev/ttyUSB*`.

### Stable Device Names (udev rules)

USB serial devices can swap between `/dev/ttyUSB0` and `/dev/ttyUSB1` after a reboot depending on enumeration order. To assign fixed names based on each FTDI adapter's unique serial number:

```bash
# Find the serial numbers for each adapter
udevadm info -a /dev/ttyUSB0 | grep '{serial}' | head -1
udevadm info -a /dev/ttyUSB1 | grep '{serial}' | head -1
```

Create a udev rule with the serial numbers:

```bash
sudo tee /etc/udev/rules.d/99-kld7.rules << 'EOF'
SUBSYSTEM=="tty", ATTRS{serial}=="FTXXXXXX", SYMLINK+="kld7_vertical"
SUBSYSTEM=="tty", ATTRS{serial}=="FTYYYYYY", SYMLINK+="kld7_horizontal"
EOF

sudo udevadm control --reload-rules && sudo udevadm trigger
```

Replace `FTXXXXXX` and `FTYYYYYY` with the actual serial numbers. Now the radars are always at `/dev/kld7_vertical` and `/dev/kld7_horizontal` regardless of plug order.

### Mounting

- **Vertical unit** — measures launch angle. Mount with the antenna plane vertical, aimed at the hitting area.
- **Horizontal unit** — measures club path / aim direction. Mount with the antenna plane horizontal.

Both should be positioned near the OPS243-A, 3-5 feet behind the tee.

### Angle Offset Calibration

The raw RADC angle needs an offset to match real launch angles. The offset depends on your mounting geometry (sensor height, angle, distance from ball).

1. Start a session with `--kld7 --kld7-angle-offset 8`
2. Hit 5-10 shots with a known club (7-iron recommended)
3. Compare reported launch angles to expected values:
   - Wedge: 24-30°, 7-iron: 16-18°, 5-iron: 12-14°, Driver: 10-14°
4. Adjust the offset: if angles read 5° too low, increase offset by 5

Typical offsets are 5-10°. The exact value depends on your mounting position.

See [K-LD7 Troubleshooting](kld7-troubleshooting.md) for more details.

## Running OpenFlight

### Kiosk Mode (Fullscreen — Recommended)

```bash
# Default: rolling buffer + sound trigger
./scripts/start-kiosk.sh

# With K-LD7 angle radar
./scripts/start-kiosk.sh --kld7 --kld7-angle-offset 8

# Mock mode (no hardware needed)
./scripts/start-kiosk.sh --mock
```

### Manual Start

```bash
openflight-server                # With radar
openflight-server --mock         # No hardware
```

Then open `http://localhost:8080`.

### Running Over SSH

```bash
DISPLAY=:0 ./scripts/start-kiosk.sh
```

## Auto-Start on Boot

### Enable the Service

```bash
sudo cp ~/openflight/scripts/openflight.service /etc/systemd/system/
sudo systemctl daemon-reload
sudo systemctl enable openflight
sudo systemctl start openflight
```

### Service Management

```bash
sudo systemctl status openflight --no-pager   # Check status
journalctl -u openflight -f                    # View logs
sudo systemctl stop openflight                 # Stop
sudo systemctl restart openflight              # Restart
sudo systemctl disable openflight              # Disable auto-start
```

To modify the service:
```bash
sudo nano /etc/systemd/system/openflight.service
sudo systemctl daemon-reload
sudo systemctl restart openflight
```

## Observability (Grafana Cloud)

OpenFlight can ship session logs to Grafana Cloud for long-term analysis.

```bash
sudo ./scripts/setup_alloy.sh
sudo vim /etc/alloy/credentials.env
```

See [observability.md](observability.md) for full setup and LogQL queries.

## Troubleshooting

### Radar Not Detected

```bash
ls /dev/ttyACM* /dev/ttyUSB*
openflight --port /dev/ttyACM0 --info
```

### Sound Trigger Not Working

See the [Sound Trigger Wiring Guide — Troubleshooting](sound-trigger-wiring.md#troubleshooting).

### K-LD7 Not Connecting

```bash
# Check USB devices
ls /dev/ttyUSB* /dev/kld7_*

# Test standalone
uv run python scripts/test_kld7.py
```

Look for `[KLD7] Connected on /dev/ttyUSB...` in the server logs. See [K-LD7 Troubleshooting](kld7-troubleshooting.md) for "Wrong length reply" and other connection issues.

### Service Won't Start

```bash
journalctl -u openflight --no-pager -n 50

# If service is masked
sudo systemctl unmask openflight
sudo cp ~/openflight/scripts/openflight.service /etc/systemd/system/
sudo systemctl daemon-reload
sudo systemctl enable openflight
```

### Slow UI Updates

Check for WebSocket instability:
```bash
journalctl -u openflight -f
```

Look for "Client disconnected/connected" messages.

### Display Issues Over SSH

Use `DISPLAY=:0` prefix for commands that need the Pi's display.

## CLI Reference

### Kiosk

```bash
./scripts/start-kiosk.sh                                      # Default
./scripts/start-kiosk.sh --mock                                # No hardware
./scripts/start-kiosk.sh --kld7 --kld7-angle-offset 8          # With angle radar
./scripts/start-kiosk.sh --port 3000                           # Custom port
```

### Server

```bash
openflight-server                    # Start with radar
openflight-server --mock             # Mock mode
openflight-server --web-port 3000    # Custom port
```

### Testing

```bash
uv run python scripts/test_rolling_buffer_persist.py --test    # Sound trigger
uv run python scripts/test_sound_trigger_hardware.py           # Direct trigger test
uv run python scripts/test_kld7.py                             # K-LD7 standalone
uv run pytest tests/ -v                                        # Full test suite
```

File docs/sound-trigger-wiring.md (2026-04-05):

# Sound Trigger Wiring Guide

Step-by-step instructions for wiring the sound trigger that enables spin detection in rolling buffer mode.

> **Parts needed:** See the [Parts List](PARTS.md#sound-trigger-for-rolling-buffer-mode) for what to buy.

## Overview

The SparkFun SEN-14262 sound detector listens for club impact and triggers the OPS243-A radar to dump its I/Q buffer. That captured data is then analyzed for spin rate estimation.

The wiring is simple — three wires:

```
SEN-14262 GATE → OPS243-A HOST_INT (J3 Pin 3)
SEN-14262 VCC  → Raspberry Pi 3.3V
SEN-14262 GND  → Raspberry Pi GND (shared with OPS243-A GND)
```

## Before You Wire: Solder R17

The SEN-14262 is designed for 5V but runs at 3.3V in this setup. At 3.3V the preamp gain is too high and the GATE output can get stuck high. To fix this, solder a through-hole resistor into the **R17** position on the SEN-14262 board.

R17 sits in parallel with the onboard 100kΩ surface-mount R3, reducing the preamp gain:

| R17 Value | Effective Resistance | Gain Reduction |
|---|---|---|
| 47kΩ | ~32kΩ | Moderate — try this first |
| 33kΩ | ~25kΩ | More aggressive — for noisy environments |

Start with 47kΩ. If the GATE LED still stays lit without sound, switch to a lower value.

---

## Wiring

### Step 1: Identify OPS243-A J3 Header Pins

```
OPS243-A J3 Header:
┌───┬───┬───┬───┬───┬───┐
│ 1 │ 2 │ 3 │ 4 │ 5 │ 6 │
│GND│   │INT│   │   │   │
└───┴───┴───┴───┴───┴───┘
```

- **Pin 1** = GND
- **Pin 3** = HOST_INT (trigger input)

### Step 2: Connect Power

1. Connect **SEN-14262 VCC** → **Pi 3.3V** (physical pin 1)
2. Connect **SEN-14262 GND** → **Pi GND** (physical pin 6)
3. Connect **OPS243-A GND (J3 Pin 1)** → same **Pi GND** rail

All three boards must share a common ground.

### Step 3: Connect Trigger

1. Connect **SEN-14262 GATE** → **OPS243-A HOST_INT (J3 Pin 3)**

That's it. No level shifter, no MOSFETs, no breadboard needed.

```
SEN-14262               Raspberry Pi           OPS243-A
┌───────────┐          ┌──────────┐          ┌──────────┐
│ VCC ──────┼──────────┤ 3.3V     │          │          │
│           │          │          │          │          │
│ GATE ─────┼──────────┼──────────┼──────────┤ HOST_INT │
│           │          │          │          │ (J3 P3)  │
│ GND ──────┼──────────┤ GND      ├──────────┤ GND      │
│           │          │          │          │ (J3 P1)  │
└───────────┘          └──────────┘          └──────────┘
```

---

## Wiring Checklist

- [ ] R17 resistor soldered on SEN-14262 board
- [ ] SEN-14262 VCC → Pi 3.3V (pin 1)
- [ ] SEN-14262 GND → Pi GND (pin 6)
- [ ] SEN-14262 GATE → OPS243-A HOST_INT (J3 Pin 3)
- [ ] OPS243-A GND (J3 Pin 1) → Pi GND (shared ground)

---

## One-Time Radar Setup

The OPS243-A must have rolling buffer mode saved to persistent memory for HOST_INT triggers to work. This is due to a firmware bug where the HOST_INT pin mode changes when transitioning modes at runtime.

```bash
# Configure and save rolling buffer mode to flash (one-time)
uv run python scripts/test_rolling_buffer_persist.py --setup

# Power cycle the radar (unplug USB, wait 3s, replug)

# Verify
uv run python scripts/test_rolling_buffer_persist.py --test
```

---

## Testing

### Quick Test: Visual

Make a loud sound near the SEN-14262. The onboard LED should flash briefly, then turn off. If the LED stays on constantly, you need a lower-value resistor in R17.

### Full Test: Software

```bash
uv run python scripts/test_sound_trigger_hardware.py
```

You should see:
```
Ready for hardware sound triggers!
Make a sound near the sensor... (Ctrl+C to quit)

[1] Waiting for hardware trigger (timeout=60s)...
  TRIGGER RECEIVED after 0.02s!
  I/Q samples: 4096 I, 4096 Q
```

---

## Troubleshooting

### GATE LED stays on (stuck high)

The preamp gain is too high for 3.3V operation.
- **Fix:** Solder a lower-value resistor into R17 (try 33kΩ instead of 47kΩ)

### No trigger received

1. Check the GATE LED flashes when you clap
2. Verify GND is shared between all three boards (Pi, SEN-14262, OPS243-A)
3. Verify HOST_INT is J3 **Pin 3** (not Pin 2)
4. Run `uv run python scripts/test_rolling_buffer_persist.py --test` to confirm radar is in rolling buffer mode

### Triggers constantly / too sensitive

- Use a lower-value R17 resistor to reduce gain
- Move the sensor further from the hitting area

### Triggers but no I/Q data

- Run the one-time radar setup (see above) — HOST_INT mode must be saved to flash
- Power cycle the radar after setup

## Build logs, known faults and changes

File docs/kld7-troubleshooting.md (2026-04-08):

# K-LD7 Troubleshooting Guide

Common issues with the K-LD7 angle radar and how to resolve them.

## Dual Radar Setup

When running two K-LD7s (vertical + horizontal), each needs:
- **Its own FTDI adapter and USB port**
- **A different base frequency** to avoid RF interference (set via `base_freq` parameter: 0=Low, 2=High)
- **A stable device name** via udev rules (see [setup guide](raspberry-pi-setup.md#stable-device-names-udev-rules)) — USB enumeration order can swap `/dev/ttyUSB0` and `/dev/ttyUSB1` after reboot

## Connection Issues

### "Wrong length reply" on startup

**Symptom:** Server fails to start with:
```
[KLD7] Connect attempt 1/5 failed: Wrong length reply
```

**Cause:** The K-LD7 was left at 3Mbaud from a prior session that crashed without sending GBYE. The kld7 library tries to INIT at 115200 baud, but the K-LD7 is still at 3Mbaud and can't parse the packet.

**Automatic recovery:** The server sends a binary GBYE packet at 3Mbaud between retry attempts to reset the K-LD7 to its idle state. This usually succeeds on attempt 2. If it doesn't recover after 5 attempts, the server exits.

**Manual recovery:** Power cycle the K-LD7 (unplug USB, wait 3 seconds, replug).

### "No K-LD7 EVAL board detected"

**Symptom:** Auto-detection can't find the K-LD7 serial port.

**Cause:** The K-LD7 uses an FTDI USB-to-serial adapter which shows up as `/dev/ttyUSB*`. If multiple USB-serial devices are connected, auto-detection may pick the wrong one.

**Fix:** Specify the port explicitly:
```bash
scripts/start-kiosk.sh --kld7 --kld7-port /dev/ttyUSB0
```

To find the correct port:
```bash
ls /dev/ttyUSB*
# or
python3 -m serial.tools.list_ports -v
```

## RADC Streaming Issues

### No RADC frames in buffer

**Symptom:** K-LD7 connects successfully but shots show `angle_source: estimated` instead of `radar`. The K-LD7 buffer log shows `NO ANGLE` or zero RADC frames.

**Check the startup logs for:**
```
[KLD7] Stream started: RADC only (3Mbaud)
[KLD7] First RADC frame received (3072 bytes)    ← must see this
[KLD7] Stream health: 50 RADC frames             ← confirms sustained streaming
```

**If "First RADC frame" never appears:**
- The K-LD7 isn't sending RADC data. Check that the connection is at 3Mbaud (the `Connected at X baud` log line).
- RADC frames are 3072 bytes each at ~18 FPS = ~55 KB/s. This requires 3Mbaud. At 115200 baud, RADC can't be transmitted in real time and the library silently drops frames.

**If "Stream crashed" appears:**
- Check the traceback. Common cause: the K-LD7 FTDI adapter disconnected or had a USB glitch. The stream thread exits and won't restart — you need to restart the server.

### "Stream ended" with running=True

**Symptom:** The `stream_frames` generator exited unexpectedly.

**Cause:** The kld7 library's `stream_frames` can exit if it receives a `DONE` frame code or encounters a packet error. This shouldn't happen during normal operation.

**Fix:** Restart the server. If it persists, check USB cable and connections.

## Angle Accuracy

### Launch angles consistently too high or too low

**Cause:** The `--kld7-angle-offset` parameter needs calibration for your mounting geometry.

**Calibration process:**
1. Hit several full shots with a known club (e.g., 7-iron)
2. Check the session log for raw RADC angles (subtract your current offset from the reported angle)
3. Compare to expected launch angles for that club:
   - Wedge: 24-30°
   - 7-iron: 16-18°
   - 5-iron: 12-14°
   - Driver: 10-14°
4. Set offset = expected angle - raw angle

```bash
# Example: raw angle is 8°, expected 7i launch is 17°, offset = 9
scripts/start-kiosk.sh --kld7 --kld7-angle-offset 9
```

### "RADC extraction returned None"

**Symptom:** K-LD7 has RADC data but can't find the ball.

**Possible causes:**
1. **Ball speed too low** — The RADC extraction uses the OPS243 ball speed to find the ball's aliased velocity bin. Below ~35 mph, the ball signal may be too weak to detect.
2. **Ball outside velocity search window** — The search window is ±10 mph around the OPS speed. If the OPS speed is wrong, the search misses.
3. **Low SNR** — The ball has a small radar cross section. Single-frame detections require SNR ≥ 5.0. Weaker signals are rejected.

**Diagnostic:** Check the K-LD7 buffer log:
```json
{"type": "kld7_buffer", "ball_angle": null, "frame_count": 68}
```
If `frame_count` is 68 (full buffer) but `ball_angle` is null, the RADC data is there but the ball wasn't found. This is normal for some shots — the ball doesn't always produce a strong enough return in the K-LD7's beam.

## Velocity Aliasing

The K-LD7 operates at RSPI=3 (100 km/h max speed). Ball speeds above 62 mph (100 km/h) alias into the negative velocity range:

| Ball Speed | Aliased Velocity | FFT Region |
|---|---|---|
| < 62 mph | Positive (no alias) | Bins 0-1024 |
| 62-124 mph | Negative (-100 to 0 km/h) | Bins 1024-2048 |
| 124-186 mph | Positive again (wraps) | Bins 0-1024 |

The RADC extraction handles aliasing automatically using the OPS243 ball speed. No user action needed.

## Antenna Spacing

The K-LD7 has two receive antennas (Rx1, Rx2) spaced 6.223 mm apart (datasheet). The RADC angle extraction uses phase interferometry between these channels. The code uses a calibrated spacing of 8.0 mm (`ANTENNA_SPACING_M` in `kld7/radc.py`) which accounts for effective electrical spacing differences.

## Serial Port Bandwidth

| Baud Rate | Throughput | RADC Capable? |
|---|---|---|
| 115200 | ~11.5 KB/s | No — RADC needs ~55 KB/s |
| 3000000 | ~300 KB/s | Yes |

The kld7 library negotiates the baud rate during INIT. OpenFlight always requests 3Mbaud for RADC support. If you see `Connected at 115200 baud` in the logs, the negotiation failed and you won't get RADC data.

## Log Lines Reference

Healthy startup sequence:
```
[KLD7] Connected on /dev/ttyUSB0 at 3000000 baud (attempt 1/5)
[KLD7] Configured: range=5m, speed=100km/h, orientation=vertical
[KLD7] Ready: port=/dev/ttyUSB0, baud=3000000, range=5m, speed=100km/h, orientation=vertical
[KLD7] Streaming started (orientation=vertical)
[KLD7] Stream started: RADC only (3Mbaud)
[KLD7] First RADC frame received (3072 bytes)
[KLD7] Stream health: 50 RADC frames
```

Per-shot angle extraction:
```
[KLD7] Angle extraction: ball_speed=87.2 mph, buffer=68 frames
[KLD7] RADC: examining 68 frames, ball_speed=87.2 mph
[KLD7] RADC: angle=8.0° speed=86.5 mph snr=10.7 conf=0.90 frames=1
```

Recovery from prior crash:
```
[KLD7] Connect attempt 1/5 failed: Wrong length reply
[KLD7] Sent GBYE at 3Mbaud to reset prior session
[KLD7] Connected on /dev/ttyUSB0 at 3000000 baud (attempt 2/5)
```

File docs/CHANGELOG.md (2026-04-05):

# Changelog

All notable changes to this project will be documented in this file.

The format is based on [Keep a Changelog](https://keepachangelog.com/en/1.1.0/),
and this project adheres to [Semantic Versioning](https://semver.org/spec/v2.0.0.html).

## [Unreleased]

### Added
- K-LD7 shot-correlation analysis workflow and theory writeup
  - `scripts/analyze_kld7.py --pair-shots` for offline club-to-ball pairing on `.pkl` captures
  - `docs/kld7-ball-detection-theory.md` with capture findings and detection rationale
- K-LD7 session-review workflow for full JSONL logs
  - `scripts/review_kld7_session.py` for per-shot profile review on `session_logs/session_*.jsonl`
  - `docs/kld7-session-review.md` documenting the empirical review method and outputs
- Persistent rolling buffer mode workaround for OPS243-A HOST_INT pin bug (per OmniPreSense)
  - `persist_rolling_buffer_mode()` method saves settings to flash memory
  - `test_rolling_buffer_persist.py` script for one-time radar setup and verification
  - Rolling buffer + sound trigger is now the default operating mode
- Grafana Alloy integration for shipping session logs to Grafana Cloud Loki
  - Setup script (`scripts/setup_alloy.sh`) and config (`config/alloy.alloy`)
  - Auto-starts with `start-kiosk.sh` when credentials are configured
  - Observability documentation with LogQL query examples
- Launch angle estimation from club type and ball speed (fallback when camera unavailable)
- Tunable Hough circle detection with all 5 parameters as CLI args (`--hough-param1`, `--hough-param2`, `--hough-min-radius`, `--hough-max-radius`, `--hough-min-dist`)
- Interactive `--tune` mode in `test_launch_angle.py` with live OpenCV trackbar sliders
- Mock mode now simulates realistic spin and launch angle data (TrackMan-based per-club averages)
- Sound trigger wiring guide with MOSFET circuit design (`docs/sound-trigger-wiring.md`)
- Camera integration with real-time ball detection in UI
- Ball detection indicator in header (shows detection status)
- Camera tab with live MJPEG stream and detection overlay
- Hough circle transform as default ball detector (replaces YOLO dependency)
- ByteTrack object tracking for persistent ball identification
- Club speed detection and smash factor calculation
- Rolling buffer mode for experimental spin rate detection
- Session logging to JSONL files (`~/openflight_sessions/`)
- I/Q streaming mode with FFT and 2D CFAR noise rejection
- `--mode rolling-buffer` flag for spin detection
- `--session-location` and `--log-dir` flags for session logging
- Roboflow API integration as optional detection backend
- YOLO performance tuning documentation for Raspberry Pi
- ONNX model export support for faster inference
- Threaded camera capture for improved FPS
- Rolling buffer spin detection documentation

### Changed
- K-LD7 launch-angle processing now uses OPS243 impact timestamps for live correlation
- K-LD7 ball-burst selection now prefers coherent far-target paths instead of averaging all far PDAT detections
- Live K-LD7 vertical launch angles now fall back to the existing club-and-speed estimate when the radar result is an obvious false positive
- Spin detection improved: Hann windowing, zero-padding to 256 points, band-limited search
- All shot metrics (spin, launch angle, club speed, carry) always shown in UI
- Shot logging unified — all metrics in single `shot_detected` entry
- Shot `mode` and `readings_data` are now proper dataclass fields (no more monkey-patching)
- Session logging enabled in mock mode for testing Alloy integration
- Default ball detection uses Hough circles instead of YOLO (no ML model required)
- Camera enabled by default in kiosk mode (use `--no-camera` to disable)
- Dropped Python 3.9 support (requires >=3.10)
- Updated Raspberry Pi setup guide with camera UI and observability instructions

## [0.2.0] - 2024-12-01

### Added
- Web UI with React frontend and Flask-SocketIO backend
- Real-time shot display with ball speed, carry distance, smash factor
- Session statistics view with per-club filtering
- Shot history with pagination
- Debug panel for radar tuning and raw readings
- Mock mode for development without hardware
- Kiosk mode script for Raspberry Pi deployment
- Systemd service for auto-start on boot
- Camera module for launch angle detection (experimental)
- Camera-based ball tracking for launch angle
- Club type selection (Driver through PW)

### Changed
- Migrated from CDM324/HB100 radar to OPS243-A
- Improved carry distance estimation model

## [0.1.0] - 2024-10-01

### Added
- Initial OPS243-A radar driver
- Basic launch monitor with shot detection
- CLI interface for monitoring shots
- Python API for integration
- Carry distance estimation based on ball speed

[Unreleased]: https://github.com/jewbetcha/openflight/compare/v0.2.0...HEAD
[0.2.0]: https://github.com/jewbetcha/openflight/compare/v0.1.0...v0.2.0
[0.1.0]: https://github.com/jewbetcha/openflight/releases/tag/v0.1.0

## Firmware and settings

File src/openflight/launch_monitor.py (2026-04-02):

"""
Golf Launch Monitor using OPS243-A Radar.

This module provides the main launch monitor functionality,
detecting golf ball speeds and displaying results.
"""

import statistics
import time
from dataclasses import dataclass, field
from datetime import datetime
from enum import Enum
from typing import Callable, List, Optional

from .ops243 import Direction, OPS243Radar, SpeedReading
from .session_logger import get_session_logger


class ClubType(Enum):
    """Golf club types for distance estimation."""

    DRIVER = "driver"
    WOOD_3 = "3-wood"
    WOOD_5 = "5-wood"
    WOOD_7 = "7-wood"
    HYBRID_3 = "3-hybrid"
    HYBRID_5 = "5-hybrid"
    HYBRID_7 = "7-hybrid"
    HYBRID_9 = "9-hybrid"
    IRON_2 = "2-iron"
    IRON_3 = "3-iron"
    IRON_4 = "4-iron"
    IRON_5 = "5-iron"
    IRON_6 = "6-iron"
    IRON_7 = "7-iron"
    IRON_8 = "8-iron"
    IRON_9 = "9-iron"
    PW = "pw"
    GW = "gw"
    SW = "sw"
    LW = "lw"
    UNKNOWN = "unknown"


# Optimal launch angles by club (from TrackMan data)
_OPTIMAL_LAUNCH = {
    ClubType.DRIVER: 11.0,
    ClubType.WOOD_3: 12.5,
    ClubType.WOOD_5: 14.0,
    ClubType.WOOD_7: 15.5,
    ClubType.HYBRID_3: 13.5,
    ClubType.HYBRID_5: 15.0,
    ClubType.HYBRID_7: 16.5,
    ClubType.HYBRID_9: 18.0,
    ClubType.IRON_2: 13.0,
    ClubType.IRON_3: 14.5,
    ClubType.IRON_4: 16.0,
    ClubType.IRON_5: 17.5,
    ClubType.IRON_6: 19.0,
    ClubType.IRON_7: 20.5,
    ClubType.IRON_8: 23.0,
    ClubType.IRON_9: 25.5,
    ClubType.PW: 28.0,
    ClubType.GW: 30.0,
    ClubType.SW: 32.0,
    ClubType.LW: 35.0,
    ClubType.UNKNOWN: 18.0,
}


def estimate_carry_distance(ball_speed_mph: float, club: ClubType = ClubType.DRIVER) -> float:
    """
    Estimate carry distance from ball speed using TrackMan-derived data.

    This uses interpolation from real-world data assuming optimal launch
    conditions (10-14° launch angle, appropriate spin for ball speed).

    Data sources:
    - TrackMan PGA Tour averages
    - pitchmarks.com ball speed to distance tables

    Args:
        ball_speed_mph: Ball speed in mph
        club: Club type (affects the model used)

    Returns:
        Estimated carry distance in yards

    Note:
        Without launch angle and spin rate, this is an approximation.
        Actual distance can vary ±10-15% based on:
        - Launch angle (optimal: 10-14° for driver)
        - Spin rate (optimal: 2000-3000 rpm for driver)
        - Weather conditions
        - Altitude
    """
    # Driver ball speed to carry distance lookup table
    # Based on TrackMan data assuming optimal launch conditions
    # Format: (ball_speed_mph, carry_yards_low, carry_yards_high)
    DRIVER_TABLE = [
        (100, 130, 142),
        (110, 157, 170),
        (120, 183, 197),
        (130, 207, 223),
        (140, 231, 249),
        (150, 254, 275),
        (160, 276, 301),
        (167, 275, 285),  # PGA Tour average
        (170, 298, 325),
        (180, 320, 349),
        (190, 342, 372),
        (200, 360, 389),
        (210, 383, 408),
    ]
    # Some source rows are mixed (e.g. PGA average vs optimal carry) and can
    # create local dips in the midpoint curve. Clamp midpoints to a
    # non-decreasing sequence so carry does not decrease as ball speed rises.
    monotonic_driver_curve = []
    max_carry_so_far = 0.0
    for speed, carry_min, carry_max in DRIVER_TABLE:
        midpoint = (carry_min + carry_max) / 2
        max_carry_so_far = max(max_carry_so_far, midpoint)
        monotonic_driver_curve.append((speed, max_carry_so_far))

    # Adjustment factors for different clubs (relative to driver)
    # Based on typical smash factors and launch conditions
    CLUB_FACTORS = {
        ClubType.DRIVER: 1.0,
        ClubType.WOOD_3: 0.96,  # Slightly less efficient
        ClubType.WOOD_5: 0.93,
        ClubType.WOOD_7: 0.91,
        ClubType.HYBRID_3: 0.91,
        ClubType.HYBRID_5: 0.89,
        ClubType.HYBRID_7: 0.87,
        ClubType.HYBRID_9: 0.85,
        ClubType.IRON_2: 0.88,
        ClubType.IRON_3: 0.87,
        ClubType.IRON_4: 0.85,
        ClubType.IRON_5: 0.82,
        ClubType.IRON_6: 0.79,
        ClubType.IRON_7: 0.76,
        ClubType.IRON_8: 0.73,
        ClubType.IRON_9: 0.70,
        ClubType.PW: 0.67,
        ClubType.GW: 0.64,
        ClubType.SW: 0.62,
        ClubType.LW: 0.61,
        ClubType.UNKNOWN: 1.0,
    }

    # Interpolate from driver table
    if ball_speed_mph <= monotonic_driver_curve[0][0]:
        # Below minimum - extrapolate linearly
        ratio = ball_speed_mph / monotonic_driver_curve[0][0]
        base_carry = monotonic_driver_curve[0][1]
        carry = base_carry * ratio
    elif ball_speed_mph >= monotonic_driver_curve[-1][0]:
        # Above maximum - extrapolate conservatively
        # Use ~1.8 yards per mph above 210 mph
        base_carry = monotonic_driver_curve[-1][1]
        carry = base_carry + (ball_speed_mph - monotonic_driver_curve[-1][0]) * 1.8
    else:
        # Interpolate between table entries
        for i in range(len(monotonic_driver_curve) - 1):
            if monotonic_driver_curve[i][0] <= ball_speed_mph < monotonic_driver_curve[i + 1][0]:
                # Linear interpolation
                speed_low, carry_low = monotonic_driver_curve[i]
                speed_high, carry_high = monotonic_driver_curve[i + 1]

                # Interpolate
                t = (ball_speed_mph - speed_low) / (speed_high - speed_low)
                carry = carry_low + t * (carry_high - carry_low)
                break
        else:
            # Fallback (shouldn't reach here)
            carry = ball_speed_mph * 1.65

    # Apply club factor
    factor = CLUB_FACTORS.get(club, 1.0)
    return carry * factor


def adjust_carry_for_launch_angle(
    base_carry: float,
    launch_angle: float,
    club: ClubType = ClubType.DRIVER,
    confidence: float = 1.0,
) -> float:
    """
    Adjust carry distance based on launch angle deviation from optimal.

    Deviation from optimal costs carry:
    - Too low: -2.0 yards per degree (ball doesn't get enough height)
    - Too high: -1.5 yards per degree (ball balloons, less severe)
    - Penalty is scaled by confidence and capped at 10% of base carry.

    Args:
        base_carry: Base carry distance in yards (from estimate_carry_distance)
        launch_angle: Measured vertical launch angle in degrees
        club: Club type (determines optimal launch angle)
        confidence: Confidence in the launch angle measurement (0-1)

    Returns:
        Adjusted carry distance in yards
    """
    optimal = _OPTIMAL_LAUNCH.get(club, 18.0)
    angle_delta = launch_angle - optimal

    if angle_delta < 0:
        raw_penalty = abs(angle_delta) * 2.0
    else:
        raw_penalty = angle_delta * 1.5

    penalty = raw_penalty * confidence
    max_penalty = base_carry * 0.10
    penalty = min(penalty, max_penalty)

    return base_carry - penalty


@dataclass
class Shot:
    """
    Represents a detected golf shot with ball and club data.

    Attributes:
        ball_speed_mph: Peak ball speed detected (mph)
        club_speed_mph: Peak club head speed detected (mph), if available
        smash_factor: Ratio of ball speed to club speed (typically 1.4-1.5 for driver)
        timestamp: When the shot was detected
        peak_magnitude: Signal strength of strongest reading
        readings: All raw speed readings for this shot
        club: Club type for distance estimation
        launch_angle_vertical: Vertical launch angle in degrees (from camera)
        launch_angle_horizontal: Horizontal launch angle in degrees (from camera)
        launch_angle_confidence: Confidence in launch angle measurement (0-1)
        spin_rpm: Spin rate in RPM (from rolling buffer mode)
        spin_confidence: Confidence in spin measurement (0-1)
        carry_spin_adjusted: Carry distance adjusted for spin (yards)
        mode: Shot source — "streaming", "rolling-buffer", or "mock"
        readings_data: Serialized readings for session logging
    """

    ball_speed_mph: float
    timestamp: datetime
    club_speed_mph: Optional[float] = None
    peak_magnitude: Optional[float] = None
    readings: List[SpeedReading] = field(default_factory=list)
    club: ClubType = ClubType.DRIVER
    launch_angle_vertical: Optional[float] = None
    launch_angle_horizontal: Optional[float] = None
    launch_angle_confidence: Optional[float] = None
    spin_rpm: Optional[float] = None
    spin_confidence: Optional[float] = None
    carry_spin_adjusted: Optional[float] = None
    mode: str = "rolling-buffer"
    readings_data: Optional[list] = None
    angle_source: Optional[str] = None  # "radar", "camera", "estimated", or None
    club_angle_deg: Optional[float] = None  # Club angle of attack from K-LD7

    @property
    def ball_speed_ms(self) -> float:
        """Ball speed in meters per second."""
        return self.ball_speed_mph * 0.44704

    @property
    def club_speed_ms(self) -> Optional[float]:
        """Club speed in meters per second."""
        if self.club_speed_mph is None:
            return None
        return self.club_speed_mph * 0.44704

    @property
    def smash_factor(self) -> Optional[float]:
        """
        Smash factor: ratio of ball speed to club speed.

        Indicates quality of contact:
        - Driver: 1.44-1.50 (optimal)
        - Irons: 1.30-1.38
        - Wedges: 1.20-1.25

        Returns:
            Smash factor or None if club speed not available
        """
        if self.club_speed_mph is None or self.club_speed_mph == 0:
            return None
        return self.ball_speed_mph / self.club_speed_mph

    @property
    def estimated_carry_yards(self) -> float:
        """Estimated carry distance based on ball speed, club type, and launch angle."""
        base = estimate_carry_distance(self.ball_speed_mph, self.club)
        if self.launch_angle_vertical is not None:
            return adjust_carry_for_launch_angle(
                base,
                self.launch_angle_vertical,
                self.club,
                self.launch_angle_confidence or 0.2,
            )
        return base

    @property
    def estimated_carry_range(self) -> tuple:
        """
        Return (min, max) carry distance estimate to show uncertainty.

        Returns:
            Tuple of (low_estimate, high_estimate) in yards
        """
        base = self.estimated_carry_yards
        # ±10% uncertainty without launch angle/spin data
        # Reduce to ±5% if we have launch angle data
        if self.has_launch_angle:
            return (base * 0.95, base * 1.05)
        return (base * 0.90, base * 1.10)

    @property
    def has_launch_angle(self) -> bool:
        """Check if launch angle data is available for this shot."""
        return self.launch_angle_vertical is not None

    @property
    def has_spin(self) -> bool:
        """Check if spin data is available for this shot."""
        return self.spin_rpm is not None

    @property
    def spin_quality(self) -> Optional[str]:
        """
        Get spin measurement quality as a string.

        Returns:
            "high", "medium", "low", or None if no spin data
        """
        if self.spin_confidence is None:
            return None
        if self.spin_confidence >= 0.7:
            return "high"
        if self.spin_confidence >= 0.4:
            return "medium"
        return "low"


class LaunchMonitor:
    """
    Golf Launch Monitor using OPS243-A Doppler Radar.

    Detects club head speed and ball speed, providing shot analysis.

    The radar with multi-object reporting (O4) detects both club and ball
    in the same sample window. Club speed is detected first during downswing
    (slower, higher magnitude due to larger radar cross-section), followed
    by ball speed after impact (faster, lower magnitude).

    Separation uses three criteria:
    1. Temporal: Club appears 0-300ms before ball
    2. Speed ratio: Club is 50-85% of ball speed (smash factor 1.1-1.7)
    3. Magnitude: Club head has larger RCS = stronger signal

    Example:
        monitor = LaunchMonitor()
        monitor.start()

        shot = monitor.wait_for_shot(timeout=30)
        if shot:
            print(f"Club Speed: {shot.club_speed_mph:.1f} mph")
            print(f"Ball Speed: {shot.ball_speed_mph:.1f} mph")
            print(f"Smash Factor: {shot.smash_factor:.2f}")
    """

    # Speed thresholds
    MIN_CLUB_SPEED_MPH = 30  # Minimum club speed (allows short game)
    MAX_CLUB_SPEED_MPH = 140  # Maximum realistic club speed
    MIN_BALL_SPEED_MPH = 30  # Minimum ball speed (allows chips/pitches)
    MAX_BALL_SPEED_MPH = 220  # Maximum realistic ball speed

    # Signal filtering
    MIN_MAGNITUDE = 20  # Minimum signal strength to accept reading
    MIN_SHOT_MAGNITUDE = 100  # Minimum peak magnitude for valid shot (filters walking)

    # Shot detection timing
    SHOT_TIMEOUT_SEC = 0.5  # Gap to consider shot complete
    MIN_READINGS_FOR_SHOT = 1  # Lowered: high-speed ball readings are transient (1-2 blocks)
    MAX_SHOT_DURATION_SEC = 0.3  # Real shots complete within 300ms

    # Club/ball separation parameters
    CLUB_BALL_WINDOW_SEC = 0.3  # Max time window for club before ball
    CLUB_SPEED_MIN_RATIO = 0.50  # Club must be >= 50% of ball speed
    CLUB_SPEED_MAX_RATIO = 0.85  # Club must be <= 85% of ball speed
    SMASH_FACTOR_MIN = 1.1  # Minimum valid smash factor
    SMASH_FACTOR_MAX = 1.7  # Maximum valid smash factor

    def __init__(
        self,
        port: Optional[str] = None,
        detect_club_speed: bool = True,
        debug: bool = False,
    ):
        """
        Initialize launch monitor.

        Args:
            port: Serial port for radar. Auto-detect if None.
            detect_club_speed: If True, attempt to detect club head speed
                              before ball speed. Requires radar to see club.
            debug: If True, print verbose debug output.
        """
        self.radar = OPS243Radar(port=port)
        self._running = False
        self._detect_club_speed = detect_club_speed
        self._debug = debug
        self._current_readings: List[SpeedReading] = []
        self._last_reading_time: float = 0
        self._shot_start_time: float = 0
        self._shots: List[Shot] = []
        self._shot_callback: Optional[Callable[[Shot], None]] = None
        self._live_callback: Optional[Callable[[SpeedReading], None]] = None
        self._current_club: ClubType = ClubType.DRIVER

    def connect(self) -> bool:
        """
        Connect to radar and configure for golf.

        Returns:
            True if successful
        """
        self.radar.connect()
        self.radar.configure_for_golf()
        return True

    def disconnect(self):
        """Disconnect from radar."""
        self.stop()
        self.radar.disconnect()

    def get_radar_info(self) -> dict:
        """Get radar module information."""
        return self.radar.get_info()

    def start(
        self,
        shot_callback: Optional[Callable[[Shot], None]] = None,
        live_callback: Optional[Callable[[SpeedReading], None]] = None,
    ):
        """
        Start monitoring for shots.

        Args:
            shot_callback: Called when a complete shot is detected
            live_callback: Called for each raw speed reading
        """
        # Stop any existing monitoring first
        if self._running:
            self.stop()

        self._shot_callback = shot_callback
        self._live_callback = live_callback
        self._running = True

        self.radar.start_streaming(self._on_reading)

    def stop(self):
        """Stop monitoring."""
        self._running = False
        self.radar.stop_streaming()
        # Process any pending readings
        if self._current_readings:
            self._process_shot()

    def _on_reading(self, reading: SpeedReading):
        """Process incoming speed readings."""
        now = time.time()
        logger = get_session_logger()

        # Call live callback if set
        if self._live_callback:
            self._live_callback(reading)

        # Filter by direction and speed
        if self._detect_club_speed:
            min_speed = self.MIN_CLUB_SPEED_MPH
        else:
            min_speed = self.MIN_BALL_SPEED_MPH

        if not min_speed <= reading.speed <= self.MAX_BALL_SPEED_MPH:
            print(
                f"[FILTER] Speed {reading.speed:.1f} outside range {min_speed}-{self.MAX_BALL_SPEED_MPH}"
            )
            return

        if reading.direction != Direction.OUTBOUND:
            print(f"[FILTER] Direction {reading.direction.value} is not outbound")
            return

        if reading.magnitude is not None and reading.magnitude < self.MIN_MAGNITUDE:
            print(
                f"[FILTER] Magnitude {reading.magnitude:.1f} below minimum {self.MIN_MAGNITUDE}"
            )
            return

        # Show timing info for debugging
        time_gap = (now - self._last_reading_time) if self._last_reading_time else 0
        print(
            f"[ACCEPTED] {reading.speed:.1f} mph {reading.direction.value} mag={reading.magnitude:.3f} "
            f"- buffered: {len(self._current_readings)}, gap: {time_gap * 1000:.0f}ms"
        )
        if logger:
            logger.log_accepted_reading(reading)

        # Check if this is part of current shot or new shot
        if self._current_readings and time_gap > self.SHOT_TIMEOUT_SEC:
            # Previous shot complete, process it
            print(
                f"[TIMEOUT] {time_gap * 1000:.0f}ms gap > {self.SHOT_TIMEOUT_SEC * 1000:.0f}ms - processing {len(self._current_readings)} readings"
            )
            self._process_shot()

        # Track shot start time
        if not self._current_readings:
            self._shot_start_time = now
            print(f"[SHOT START] Beginning new shot window")

        # Add to current readings
        self._current_readings.append(reading)
        self._last_reading_time = now

    def _find_club_speed(
        self, readings: List[SpeedReading], ball_speed: float, ball_time: float
    ) -> Optional[SpeedReading]:
        """
        Find club head reading using temporal and magnitude analysis.

        Args:
            readings: Sorted list of readings (by timestamp)
            ball_speed: Detected ball speed in mph
            ball_time: Timestamp of ball reading

        Returns:
            Club SpeedReading if found, None otherwise
        """
        if len(readings) < 2:
            return None

        # Speed range: club should be 50-85% of ball speed
        club_speed_min = max(self.MIN_CLUB_SPEED_MPH, ball_speed * self.CLUB_SPEED_MIN_RATIO)
        club_speed_max = min(self.MAX_CLUB_SPEED_MPH, ball_speed * self.CLUB_SPEED_MAX_RATIO)

        # Find candidate club readings (before ball, in speed range)
        club_candidates = []
        for r in readings:
            r_time = r.timestamp or 0

            # Must be before the ball reading
            if r_time >= ball_time:
                continue

            # Must be within time window (not too early)
            if ball_time - r_time > self.CLUB_BALL_WINDOW_SEC:
                continue

            # Must be in realistic club speed range
            if not (club_speed_min <= r.speed <= club_speed_max):
                continue

            # Must be less than ball speed
            if r.speed >= ball_speed:
                continue

            club_candidates.append(r)
            print(
                f"[CLUB CANDIDATE] {r.speed:.1f} mph, mag={r.magnitude}, "
                f"dt={((ball_time - r_time) * 1000):.0f}ms before ball"
            )

        if not club_candidates:
            return None

        # Select best candidate: prefer highest magnitude (larger RCS = club head)
        candidates_with_mag = [c for c in club_candidates if c.magnitude]

        if candidates_with_mag:
            club_reading = max(candidates_with_mag, key=lambda r: r.magnitude)
            print(
                f"[CLUB DETECTED] {club_reading.speed:.1f} mph selected by magnitude "
                f"(mag={club_reading.magnitude})"
            )
        else:
            # No magnitude data - use reading closest in time to ball
            club_reading = max(club_candidates, key=lambda r: r.timestamp or 0)
            print(f"[CLUB DETECTED] {club_reading.speed:.1f} mph selected by timing")

        # Validate smash factor
        smash = ball_speed / club_reading.speed
        if not (self.SMASH_FACTOR_MIN <= smash <= self.SMASH_FACTOR_MAX):
            print(
                f"[CLUB REJECTED] Smash factor {smash:.2f} outside range "
                f"{self.SMASH_FACTOR_MIN}-{self.SMASH_FACTOR_MAX}"
            )
            return None

        return club_reading

    def _process_shot(self):
        """
        Process accumulated readings into a shot.

        Uses temporal and magnitude-based analysis to separate club from ball:
        1. Ball speed = peak (maximum) speed in the shot window
        2. Club speed = detected BEFORE ball, lower speed, higher magnitude

        Validates that the readings represent a real golf shot:
        - Sufficient readings clustered in time (<300ms)
        - Peak magnitude above threshold (strong radar return)
        - Ball speed above minimum for golf shots
        """
        if len(self._current_readings) < self.MIN_READINGS_FOR_SHOT:
            speeds = [f"{r.speed:.1f}" for r in self._current_readings]
            print(
                f"[REJECTED] Only {len(self._current_readings)} readings "
                f"(need {self.MIN_READINGS_FOR_SHOT}): {', '.join(speeds)} mph"
            )
            self._current_readings = []
            return

        # Sort readings by timestamp for temporal analysis
        sorted_readings = sorted(self._current_readings, key=lambda r: r.timestamp or 0)
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

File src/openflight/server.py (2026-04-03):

"""
WebSocket server for OpenFlight UI.

Provides real-time shot data to the web frontend via Flask-SocketIO.
"""

import json
import logging
import os
import random
import statistics
import threading
import time
from datetime import datetime
from pathlib import Path
from typing import List, Optional

from flask import Flask, Response, send_from_directory
from flask_cors import CORS
from flask_socketio import SocketIO

from .launch_monitor import ClubType, Shot
from .ops243 import Direction, SpeedReading, set_show_raw_readings
from .rolling_buffer.monitor import estimate_carry_with_spin, get_optimal_spin_for_ball_speed
from .session_logger import get_session_logger, init_session_logger

# Configure logging
logger = logging.getLogger(__name__)

# Camera imports (optional)
try:
    import cv2

    from .camera_tracker import CameraTracker

    CV2_AVAILABLE = True
except ImportError:
    CV2_AVAILABLE = False
    CameraTracker = None

try:
    from picamera2 import Picamera2

    PICAMERA_AVAILABLE = True
except ImportError:
    PICAMERA_AVAILABLE = False


app = Flask(__name__, static_folder="../../ui/dist", static_url_path="")
CORS(app)
socketio = SocketIO(app, cors_allowed_origins="*", async_mode="threading")

# Global state
monitor = None
mock_mode: bool = False
debug_mode: bool = False
debug_log_file = None
debug_log_path: Optional[Path] = None

# K-LD7 angle radar
kld7_tracker = None

# Camera state
camera: Optional["Picamera2"] = None
camera_tracker: Optional["CameraTracker"] = None
camera_enabled: bool = False
camera_streaming: bool = False
camera_thread: Optional[threading.Thread] = None
camera_stop_event: Optional[threading.Event] = None
ball_detected: bool = False
ball_detection_confidence: float = 0.0
latest_frame: Optional[bytes] = None
frame_lock = threading.Lock()


# Baseline launch angles by club (TrackMan data)
# Format: (avg_launch_deg, avg_ball_speed_mph, deg_per_mph_deviation)
_CLUB_LAUNCH_MODEL = {
    ClubType.DRIVER: (11.0, 143, 0.15),
    ClubType.WOOD_3: (12.5, 135, 0.18),
    ClubType.WOOD_5: (14.0, 128, 0.20),
    ClubType.WOOD_7: (15.5, 122, 0.20),
    ClubType.HYBRID_3: (13.5, 123, 0.22),
    ClubType.HYBRID_5: (15.0, 118, 0.22),
    ClubType.HYBRID_7: (16.5, 112, 0.25),
    ClubType.HYBRID_9: (18.0, 106, 0.25),
    ClubType.IRON_2: (13.0, 120, 0.25),
    ClubType.IRON_3: (14.5, 118, 0.25),
    ClubType.IRON_4: (16.0, 114, 0.28),
    ClubType.IRON_5: (17.5, 110, 0.28),
    ClubType.IRON_6: (19.0, 105, 0.30),
    ClubType.IRON_7: (20.5, 100, 0.30),
    ClubType.IRON_8: (23.0, 94, 0.30),
    ClubType.IRON_9: (25.5, 88, 0.30),
    ClubType.PW: (28.0, 82, 0.30),
    ClubType.GW: (30.0, 76, 0.30),
    ClubType.SW: (32.0, 73, 0.30),
    ClubType.LW: (35.0, 70, 0.30),
    ClubType.UNKNOWN: (18.0, 120, 0.25),
}

# Optimal smash factor by club type (ball_speed / club_speed)
_OPTIMAL_SMASH = {
    ClubType.DRIVER: 1.48,
    ClubType.WOOD_3: 1.44,
    ClubType.WOOD_5: 1.42,
    ClubType.WOOD_7: 1.42,
    ClubType.HYBRID_3: 1.39,
    ClubType.HYBRID_5: 1.38,
    ClubType.HYBRID_7: 1.37,
    ClubType.HYBRID_9: 1.36,
    ClubType.IRON_2: 1.37,
    ClubType.IRON_3: 1.36,
    ClubType.IRON_4: 1.35,
    ClubType.IRON_5: 1.35,
    ClubType.IRON_6: 1.34,
    ClubType.IRON_7: 1.34,
    ClubType.IRON_8: 1.33,
    ClubType.IRON_9: 1.33,
    ClubType.PW: 1.25,
    ClubType.GW: 1.23,
    ClubType.SW: 1.22,
    ClubType.LW: 1.20,
    ClubType.UNKNOWN: 1.35,
}

# Max smash factor adjustment in degrees (clamped to prevent floor-dependence)
_MAX_SMASH_ADJ_LOW = -3.0  # max degrees to subtract for thin/toe hits
_MAX_SMASH_ADJ_HIGH = 2.0  # max degrees to add for high-face hits

# Degrees of launch angle change per 0.01 smash factor unit
_SMASH_DEG_PER_HUNDREDTH_LOW = 0.4  # below optimal (thin hits penalized more)
_SMASH_DEG_PER_HUNDREDTH_HIGH = 0.2  # above optimal

# Spin rate adjustment: degrees per 500 rpm deviation from optimal
_SPIN_DEG_PER_500RPM = 0.3
# Max spin adjustment in degrees (clamped like smash)
_MAX_SPIN_ADJ = 2.0

# Radar launch sanity guard. These windows are intentionally wide:
# they are meant to catch obvious K-LD7 false positives, not to micromanage
# normal shot-to-shot variation or mishits.
_RADAR_SANITY_LOW_CONF_BONUS_DEG = 5.0


def estimate_launch_angle(
    club: ClubType,
    ball_speed_mph: float,
    club_speed_mph: Optional[float] = None,
    spin_rpm: Optional[float] = None,
) -> tuple:
    """
    Estimate launch angle from club type, ball speed, and optional smash/spin data.

    Uses TrackMan averages as baseline, then adjusts for:
    - Ball speed deviation from club average
    - Smash factor deviation from optimal (if club_speed provided)
    - Spin rate deviation from optimal (if spin_rpm provided)

    Returns (vertical_angle, confidence).
    """
    avg_launch, avg_speed, deg_per_mph = _CLUB_LAUNCH_MODEL.get(club, (18.0, 120, 0.25))

    # Slower than average → higher launch, faster → lower launch
    speed_delta = ball_speed_mph - avg_speed
    adjustment = -speed_delta * deg_per_mph

    confidence = 0.2

    # Smash factor adjustment: compare actual smash to optimal for this club
    if club_speed_mph is not None and club_speed_mph > 0:
        smash_factor = ball_speed_mph / club_speed_mph
        optimal_smash = _OPTIMAL_SMASH.get(club, 1.35)
        smash_delta = smash_factor - optimal_smash

        if smash_delta < 0:
            smash_adj = max(_MAX_SMASH_ADJ_LOW, smash_delta * 100 * _SMASH_DEG_PER_HUNDREDTH_LOW)
        else:
            smash_adj = min(_MAX_SMASH_ADJ_HIGH, smash_delta * 100 * _SMASH_DEG_PER_HUNDREDTH_HIGH)
        adjustment += smash_adj

        confidence = 0.35

    # Spin rate adjustment: compare actual spin to optimal for this club/speed
    if spin_rpm is not None and spin_rpm > 0:
        optimal_spin = get_optimal_spin_for_ball_speed(ball_speed_mph, club)
        spin_delta = spin_rpm - optimal_spin
        spin_adj = (spin_delta / 500.0) * _SPIN_DEG_PER_500RPM
        spin_adj = max(-_MAX_SPIN_ADJ, min(_MAX_SPIN_ADJ, spin_adj))
        adjustment += spin_adj

        if confidence >= 0.35:
            confidence = 0.5
        else:
            confidence = 0.35

    launch_angle = max(5.0, round(avg_launch + adjustment, 1))

    return (launch_angle, confidence)


def _radar_launch_base_delta_deg(club: ClubType) -> float:
    """Return a conservative club-family window for radar launch sanity checks."""
    if club in {ClubType.PW, ClubType.GW, ClubType.SW, ClubType.LW}:
        return 22.0
    if club in {ClubType.IRON_6, ClubType.IRON_7, ClubType.IRON_8, ClubType.IRON_9}:
        return 20.0
    return 18.0
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

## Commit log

2026-03-01 [cr] fix camera constructor
    [server.py]
2026-03-03 Add implementation plan for enhanced launch angle estimation
    6-task TDD plan: smash factor adjustment, spin adjustment, carry
    distance integration, and server wiring.
2026-03-03 Improve smash factor adjustment: clamp coefficients, stronger tests
    - Move lookup tables to module-level constants
    - Clamp smash adjustment to [-3, +2] degrees to prevent floor-dependence
    - Name coefficient constants explicitly
    - Add test_high_smash_raises_launch and test_zero_club_speed_ignored
    - Strengthen existing test assertions with magnitude bounds
    [server.py]
2026-03-03 [cr] add spin rate adjustment to launch angle estimation
    Spin rpm deviation from optimal (per club/speed) nudges launch angle
    up or down at 0.3 deg per 500 rpm, clamped to +/-2 deg. Confidence
    bumps to 0.35 (spin only) or 0.5 (smash + spin).
2026-03-03 feat: add spin rate adjustment to launch angle estimation
    Uses get_optimal_spin_for_ball_speed() to compare actual spin to
    optimal. High spin nudges launch angle up, low spin nudges down.
    Clamped to [-2, +2] degrees. Confidence tiers: 0.2 (speed only),
    0.35 (smash or spin), 0.5 (both).
2026-04-02 Revert "fix: preserve HOST_INT by skipping GC mode transition for sound trigger"
    This reverts commit 5de90f8e32d29a404c9924ad0e06992bcf72611d.
    [monitor.py, ops243.py]
2026-04-03 fix: carry_spin_adjusted, angle offset, and ball speed validation
    Three fixes from live session analysis (session_20260403_130720):
    1. carry_spin_adjusted always None: the server never called
    estimate_carry_with_spin() even when spin_rpm was present on the
    shot. Now computed in on_shot_detected when spin data is available.
    2. K-LD7 angles consistently ~12-15° below expected: added
    angle_offset_deg parameter to KLD7Tracker (default 0.0) to correct
    for sensor mounting tilt. Wired through --kld7-angle-offset CLI arg
    and start-kiosk.sh. Applied to both ball and club angle outputs.
    3. Ball speed validation (indentation fix from prior commit) confirmed
    working — false trigg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
    [server.py, tracker.py]
2026-04-06 [cr] use speed from OPS as filter for kld7 raw ADC
2026-04-07 Added step file and logo
    [MainLogo.DXF, OpenFlight.STEP]
